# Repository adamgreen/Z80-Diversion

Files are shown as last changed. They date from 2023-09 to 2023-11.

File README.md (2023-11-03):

# Z80 Diversion
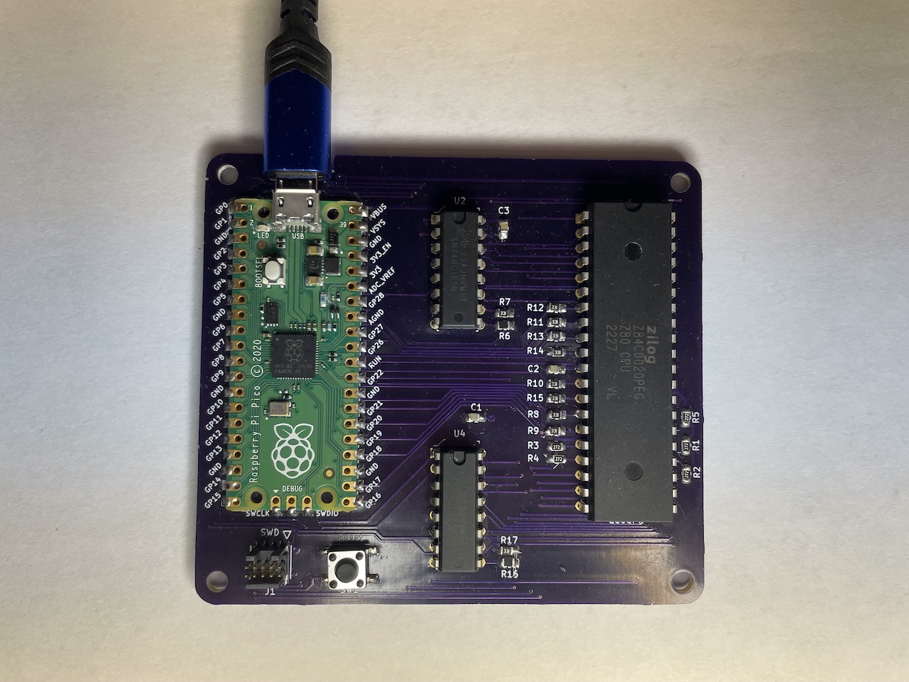
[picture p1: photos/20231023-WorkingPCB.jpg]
Photo of Working PCB


This project is a [Z80](https://www.zilog.com/index.php?Itemid=26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) based single board computer. A [RP2040 microcontroller](https://www.raspberrypi.com/documentation/microcontrollers/rp2040.html) is also included on the board. It is connected to the Z80 bus to:
* Provide the Z80 access to 64k of its 264k of SRAM.
* Allow a [Z80 compatible version of GDB](https://github.com/b-s-a/binutils-gdb) to debug the Z80 over a USB serial connection. The RP2040 is used as a hardware debugger for the Z80 much like modern JTAG or SWD probes (ie. Segger J-Link).

## Project Purpose
I want to verify some unit tests which exercise all of the instructions supported by the Z80 microprocessor. These tests can be used to verify Z80 emulation. Having the ability to also runs these tests against real Z80 hardware is desireable as it allows verifying the quality of the tests themselves. A few years ago, I did something similar for the ARMv6-M instruction tests that I wrote for my [pinkySim project](https://github.com/adamgreen/pinkySim).

## Project Progression
* The Z80, RP2040 Pico, and SN74HC165 shift register devices arrived from Digikey.
* I completed the initial schematic in KiCAD.
* I wired up an initial test version on my breadboard.
* I wrote simple proof of concept PIO and ARM code for the RP2040 to verify my hardware setup.
* I completed the initial PCB design in KiCAD.
* I ordered and received PCBs from [OSHPark](https://oshpark.com).
* I was able to download a [Z80 port of binutils/GDB](https://github.com/b-s-a/binutils-gdb) and build it on my Mac.
* I soldered up one of the PCBs and successfully tested it out with the code that I had previously developed.
* I simplified the PIO state machine code and got it running faster:
  * Can run the Z80 at 500kHz without requiring any wait cycles.
  * Can run the Z80 at faster clock rates (at least 5MHz) reliably but requires wait cycles as the RP2040 takes time to wait for the shift registers and respond to memory read/write requests.
* My [MRI core](https://github.com/adamgreen/mri) has been extended to handle debug targets which aren't just 32-bit. This will allow 64-bit in the future and 16-bit for Z80 debugging.
* The Z80 version of GDB is now able connect to the board via a RP2040 USB based serial connection to:
  * Examine and modify the Z80's 64k of RAM (which is actually a 64k global buffer on the RP2040).
  * Examine and modify the Z80's registers.
  * Single step the Z80.
  * Set up to 4 Code Breakpoints.
  * Set up to 2 Data Watchpoints
  * Z80 reset from GDB.

## Reading List
Build Your Own Z80 Computer Book Cover<br>
It has been around a decade since I last looked at the Z80 so I had to skim through a few Z80 references to refresh my memory of what it takes to interface this little guy to the outside world. These references included:
* [Build Your Own Z80 Computer by Steve Ciarcia](https://en.wikipedia.org/wiki/Build_Your_Own_Z80_Computer) ([Free PDF](http://www.pestingers.net/pdfs/other-computers/build-your-own-z80.pdf)).
* [Z80 CPU User Manual](https://www.zilog.com/docs/z80/UM0080.pdf)
* [Z80 Product Specification](https://www.zilog.com/docs/z80/ps0178.pdf)
* [Other Official Z80 Documents](https://www.zilog.com/index.php?Itemid=26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)

I also skimmed some RP2040 documentation again as well to make sure that I had a good chance of successfully interfacing it to the Z80 before going too far down that path:
* [Raspberry Pi Pico Datasheet](https://datasheets.raspberrypi.com/pico/pico-datasheet.pdf)
* [RP2040 Datasheet](https://datasheets.raspberrypi.com/rp2040/rp2040-datasheet.pdf)

## High Level BOM
This board includes:
* A **Z80 Microprocessor** - I am using a [Z84C0020PEG](https://www.digikey.com/en/products/detail/zilog/Z84C0020PEG/928994) device since it is:
  * 20 MHz capable. I picked the fastest CMOS version of the device available. It can run at 20MHz when powered by a 5V supply but it should be able to run at a lower 3.3V (same as the RP2040) when clocked at lower frequencies (between 1 and 2.5 MHz).
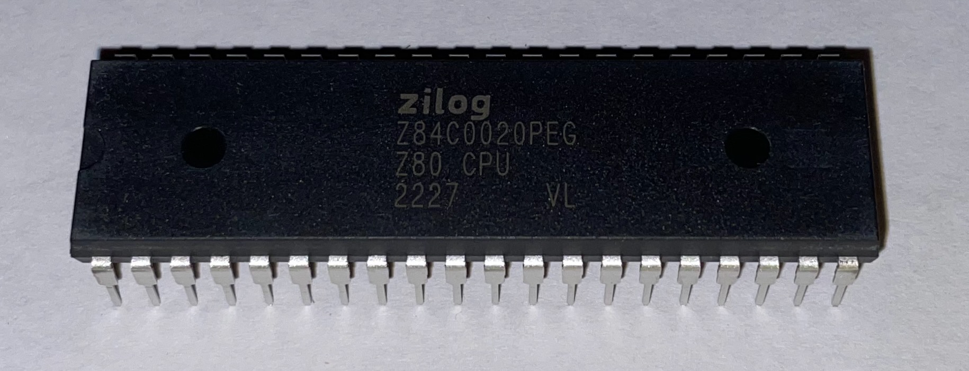
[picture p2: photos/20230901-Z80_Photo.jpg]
Photo of Z80 IC
  * 40-pin DIP package. Currently Digikey only has the DIP version of the 20MHz capable part in stock. I would have preferred the LQFP SMD version but it doesn't look like it will be in stock for awhile. It did make early bread boarding possible though.<br>
* A [RP2040 based Pico](https://www.digikey.com/en/products/detail/raspberry-pi/SC0915/13624793). This is connected to the Z80 bus and used to service Z80 memory requests. It also functions as a hardware debugger for the Z80. Features of the RP2040 that have been leveraged for this project include:
  * USB 1.1 controller and PHY. This allows for easy connection to a desktop/laptop. GDB can be used to program and debug the Z80 over this USB connection.
  * 264kB SRAM. 64kB of this is used to service memory read/write requests from the Z80.
  * 2MB of FLASH. Lots of room for the required firmware and storage of any ROM images that we may want to use with the Z80.
  * Programmable I/O. This was useful for interfacing with the Z80 bus without bit banging everything from the CPU.
  * Dual core Cortex-M0+ cores. Allowed dedicating a core to just servicing memory read/writes requests from the Z80. This way things like USB interrupts don't introduce random delays.
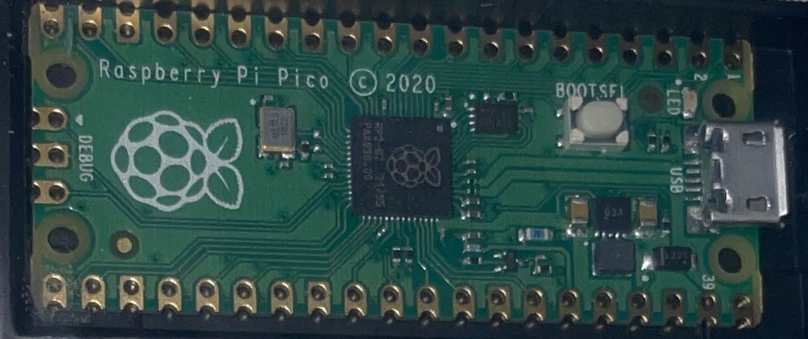
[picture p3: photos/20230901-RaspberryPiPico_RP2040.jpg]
Photo of Raspberry Pi Pico
  * The Pico has the required voltage regulation to allow the board to be powered directly from USB.<br>
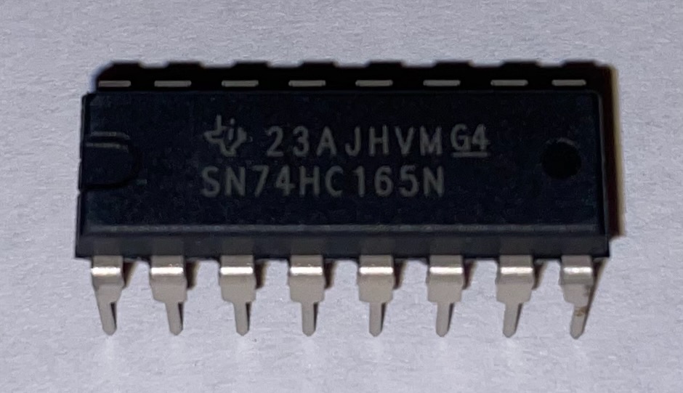
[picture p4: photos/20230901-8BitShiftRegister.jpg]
Photo of 8-bit Shift Register
* 2 x [SN74HC165 8-bit shift registers](https://www.digikey.com/en/products/detail/texas-instruments/SN74HC165N/376966). This is used to latch the 16-bit address sent from the Z80 and push it into the RP2040 over 2 serial lines, one for the even bits and the other for the odd bits. I run this chip at 5V and run the serial outputs through a 3/5 voltage divider to make it compatible with the RP2040 while also allowing it to run faster. The voltage divider did end up slowing down the rise/fall times but running it at 3.3V slowed it down even more. I ended up clocking the shift registers at ~15MHz with an asymmetric clock. I hold it high for longer so that the output has time to stabilize before I sample it from the RP2040 on the falling clock edge. I would like to switch to a faster shift register in future revisions.<br>

## Programmable I/O
One of the coolest features of the RP2040 is its Programmable I/O (PIO). If you look at the block diagram of many peripherals on a microcontroller, you tend to see the same parts: inbound and outbound FIFOs, shift registers, pin I/O, and a **state machine**. The PIO has all of the same parts except that its state machine is programmable.

I leverage the programmable I/O (PIO) peripheral on the RP2040 for interfacing to the Z80 bus. I use 2 PIO state machines for this interfacing:
* The first state machine, ```AddressStateMachine```, samples the **MREQ'** / **IOREQ'** signals and shifts out the 16-bit address bits using two 8-bit shift registers:
  * It pauses if it sees **RFSH'** asserted (pulled low) since those requests are just for refreshing DRAM which can be safely ignored. Once this signal is de-asserted the state machine starts running again.
  * If it sees either of the **MREQ'** or **IOREQ'** signals go active (pulled low) then it asserts the **WAIT'** signal to let the Z80 know that it needs to wait for the RP2040 to access the requested data.
  * It will then latch the 16-bit address bits and start shifting out the address, two bits at a time.
  * Once the 16-bit address has been fully shifted in, it will be pushed to the RX FIFO for the CPU to pick up.
  * The state machine will then wait for the CPU to send back the PIO instruction that either waits on the **MREQ'** or **IOREQ'** signal being de-asserted.
  * Before executing the wait instruction it de-asserts the **WAIT'** signal to let the Z80 know that the request has been completed.
  * It then waits for the **MREQ'** or **IOREQ'** signal to be de-asserted (pulled high again) before looping around and looking for the next request. The CPU assembles the correct ```WAIT 1 GPIO n``` instruction and sends it down to the PIO state machine via its TX FIFO.
* The other state machine, ```ReadWriteStateMachine```, samples the **RD'**/**WR'** signals to determine if a read or write memory transfer is being requested by the Z80:
  * It keeps sampling the **RD'**/**WR'** signals until it sees one of them go active (pulled low).
  * The state of the **RD'**, **WR'**, **D0** - **D7** and **M1'** lines are then transferred to the CPU so that between this data and the 16-bit address from the other state machine, the CPU has enough information to perform the memory request.
  * The state machine will then wait for the CPU to send back the required response. This will include bits needed for setting **D0**-**D7** to the correct input/output state, the requested byte if a read request was made, bits to set **D0**-**D7** back to input only, and a PIO instruction that waits on the **RD'** or **WR'** signal being de-asserted.

## Current Pin Map
The PIO state machines place constraints on some signals as they will need to be mapped to consecutively numbered GPIO pins so that they can be shifted in/out as a unit. This is how the pins ended up being mapped between the RP2040 and Z80:
| RP2040 | Z80 / Shift | PIO Pin Group | Notes |
|---|---|---|---|
| GP0  | Shift_In_Even | Input | |
| GP1  | Shift_In_Odd  | Input | |
| GP2  | MREQ' | Input | |
| GP3  | IOREQ' | Input | |
| GP4  | CLK | Set | |
| GP5  | Shift_Clock | Side Set | |
| GP6  | Shift_Latch | Side Set | |
| GP7  | RD' | Input | |
| GP8  | WR' | Input | |
| GP9  | D0 | Input/Output | |
| GP10 | D1 | Input/Output | |
| GP11 | D2 | Input/Output | |
| GP12 | D3 | Input/Output | |
| GP13 | D4 | Input/Output | |
| GP14 | D5 | Input/Output | |
| GP15 | D6 | Input/Output | |
| GP16 | D7 | Input/Output | |
| GP17 | M1' | Input | |
| GP18 | WAIT' | Set | 2.2kΩ Pull-Up |
| GP19 | RFSH' | WAIT GPIO | |
| GP20 | HALT' | Input / Non-PIO  | |
| GP21 | NMI' | Output / Non-PIO | 2.2kΩ Pull-Up |
| GP22 | INT' | Output / Non-PIO | 2.2kΩ Pull-Up |
| GP26 | RESET' | Output / Non-PIO | 3 CLK Long Pulse (3µs @ 1MHz) |
| N/C  | BUSREQ' | Not Connected | 2.2kΩ Pull-Up |

## Current Schematic
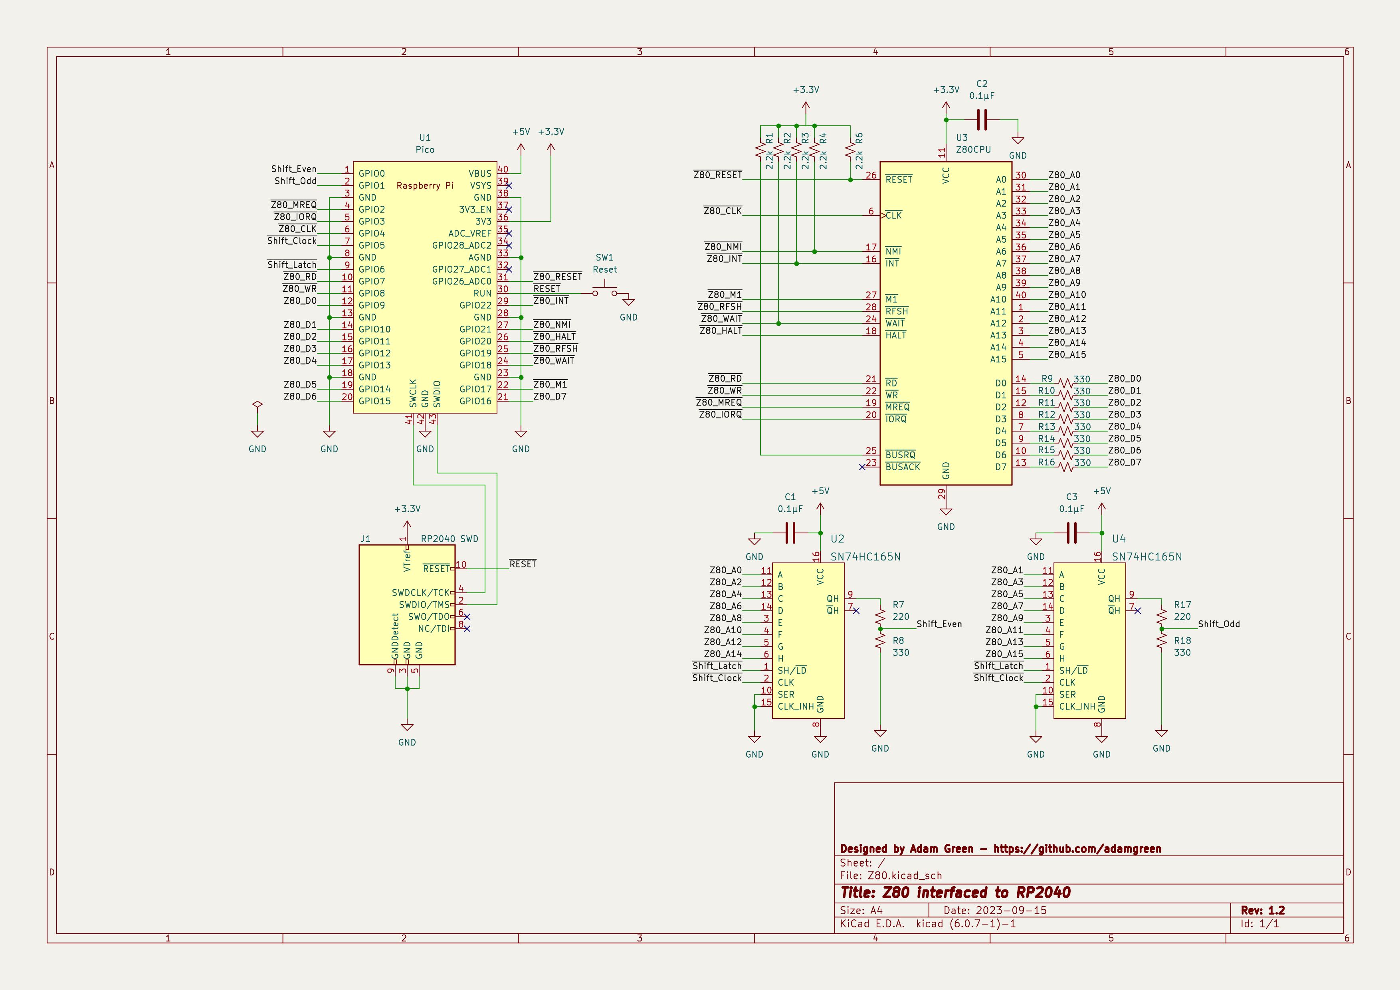
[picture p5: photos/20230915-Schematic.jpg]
Current Schematic
<br>
After wiring up this circuit on a breadboard, I found that things worked better if I made some changes to my original schematic:
* I originally thought it would work best to shift in the Z80 address bit pairs in from least significant to most significant. This results in the CPU receiving the address in the upper 16 bits and the **MREQ'** and **IOREQ'** signals values in bits 14-15. It would be nicer if the address bits were in the lower 16-bits where they can be easily masked off and used. Doing the shifts in this order required me reversing the order of the Z80 address bit connections to each of the shift registers.
* I added 0.1µF bypass capacitors to the IC power supply lines.
* I discovered that the SN74HC165 shift registers didn't have output rise and fall times that were consistent with running them at 50MHz even though I was supplying them with 5V.
  * The high resistance voltage divider I had in the original schematic to level shift this output made the problem worse.
  * Reducing the voltage divider from 55kΩ to 550Ω did shorten the rise and fall times but not enough to work at 50MHz. It does work up to 15MHz now though.
  * If I switch to SMD parts then I think there are variants of the 74*165 shift registers that can run at 3.3V and give the desired <= 10ns rise/fall times. I may try this in the future but I will just use the parts that I already have for now.
* I also wanted to test that the Z80 runs reliably at 3.3V with lower clock rates. The Z80 didn't hit any issues running NOPs at 400kHz on this breadboard setup. After I rewrote the PIO code when working with the PCB version of this circuit I was able to run it successfully at 5MHz.
* I removed the 330Ω pull-up resistor from the **CLK** signal. It was needed for TTL clocking circuits used with the older NMOS version of the Z80. I am using a CMOS version of the Z80 and driving **CLK** directly from a pin of the CMOS based RP2040 microcontroller so it isn't needed anymore.

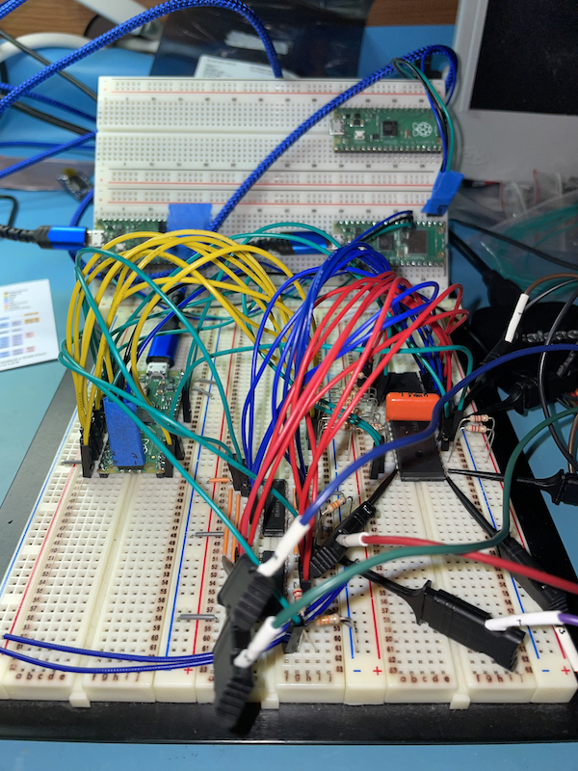
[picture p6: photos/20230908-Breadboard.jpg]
Photo of Breadboard Setup


The screenshot below shows some early traces from my logic analyzer as I began to get the Z80 successfully starting up on the breadboard above and executing NOPs supplied by the RP2040.

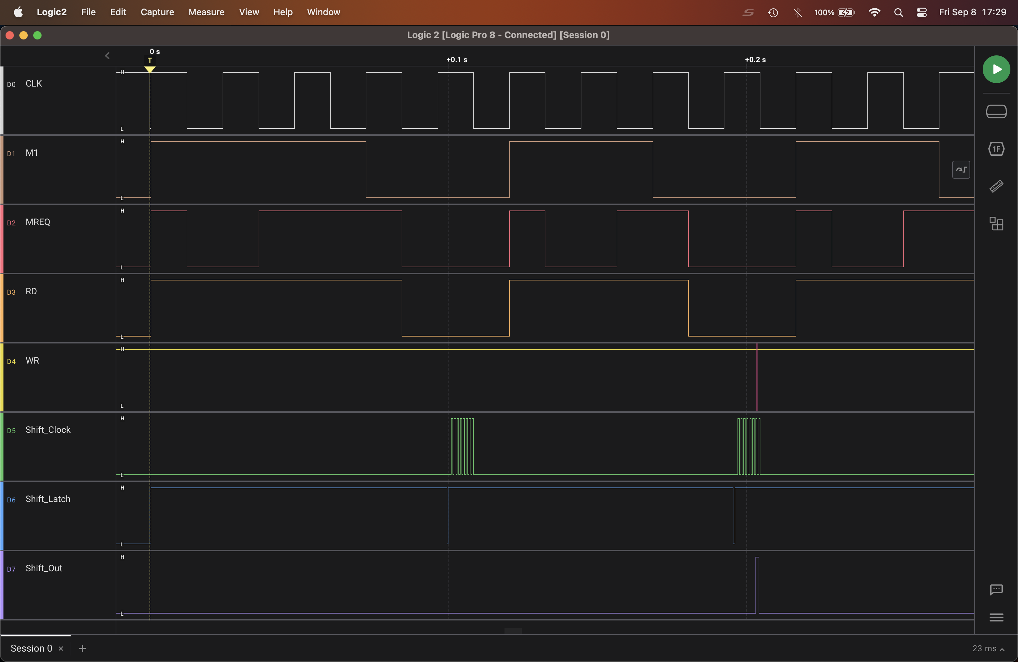
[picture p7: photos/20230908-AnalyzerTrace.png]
Initial Trace


## PCB Design version 1.1
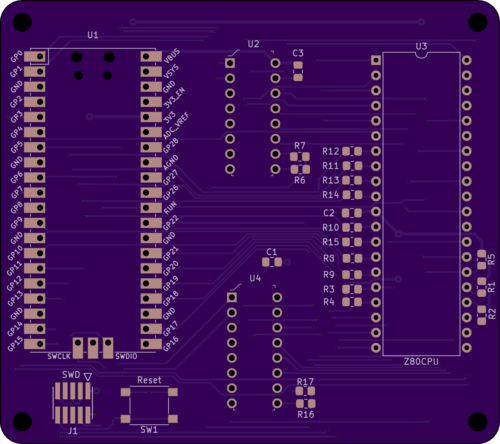
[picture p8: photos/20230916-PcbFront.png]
OSHPark rendering of PCB Front
<br>
I completed the initial PCB design and sent it off to OSHPark to have it fabricated. It was a lot easier to work with this board than the previous mess of wires I had on my breadboard.

### Issues Discovered in Version 1.1 PCB
After soldering up the first of the version 1.1 PCBs I encountered an issue:
* When soldering the Raspberry Pi Pico to the PCB as a surface mount part there isn't enough clearance between the bottom of the USB connector on the Pico and my PCB.
  * I had to file out a groove to have it work with my USB cable on the first board I soldered up since I had already soldered the Pico down flat to the PCB surface.
  * On subsequent assemblies of this version of the PCB I will use male headers to mount the Pico as a through hole part (the footprint allows both SMD and through hole mounting). This will lift the Pico up off of the PCB to make room for the USB cable housing.
  * If I make another version of this PCB, I will align the Pico's USB connector with the edge of the PCB to eliminate this issue.

## GDB for Z80
I have past experience with using GDB and GDB debug stubs to debug Cortex-M microcontrollers. I leveraged this experience to support GDB debugging of the Z80 on this board. When I tested my ARMv6-M instruction tests on real Cortex-M hardware, I used an existing GDB debug stub and modified my test harness to pretend to be GDB so that it could place required inputs and code into RAM, setup the registers, single step over the test instruction, and then interrogate memory and registers afterwards to verify that the expected side effects occurred. I can now do the same for the Z80 using this project.

I found the following page on the web and it had lots of great information on how to use GDB with the Z80:
* [chciken's TLMBoy: Implementing the GDB Remote Serial Protocol](https://www.chciken.com/tlmboy/2022/04/03/gdb-z80.html)

### Building GDB for Z80
I have been able to download and build the same Z80 fork as @chciken:
* ```git clone https://github.com/b-s-a/binutils-gdb.git z80-gdb```
* Apply the following diff to allow the Z80 version of GDB to handle SP being set to 0x0000:
```diff
diff --git a/gdb/z80-tdep.c b/gdb/z80-tdep.c
index 641af5e06c..42f04c49f0 100644
--- a/gdb/z80-tdep.c
+++ b/gdb/z80-tdep.c
@@ -663,6 +663,7 @@ z80_frame_unwind_cache (struct frame_info *this_frame,
       /* Assume that the FP is this frame's SP but with that pushed
         stack space added back.  */
       this_base = get_frame_register_unsigned (this_frame, Z80_SP_REGNUM);
+      if (this_base == 0x0000) this_base = 1 << gdbarch_ptr_bit(gdbarch);
       sp = this_base + info->size;
       if (this_base < sp_min || sp > sp_max)
          return info;
```
* ```brew install texinfo```
* ```cd z80-gdb```
* ```mkdir build/```
* ```cd build/```
* ```LDFLAGS=-Bstatic ../configure --target=z80-unknown-elf --disable-werror --prefix=$(pwd) --exec-prefix=$(pwd)```
* ```make```
* **Note:** I don't have ```make install``` working on macOS yet. Until then, the GDB binary can be found as ```z80-gdb/build/gdb/gdb```

### Using GDB for Z80
This section shows a few snippets from an example GDB session where it is attached to my Z80 board and uses them to explain some of the debug operations supported by my firmware.

* First I will start the Z80 version of GDB that I talked about building up above. It instructs GDB to connect to a remote target using a virtual serial port, ```/dev/cu.usbmodem111301``` on my machine. GDB will give a warning about ```"No executable has been specified and target does not support determining executable automatically."``` because no .ELF file was provided. This means we have no symbols but we can still look at the low level assembly instructions, Z80 registers, and memory contents to figure out what our program is doing.
* The firmware in my board is currently written so that it loads a little test program into memory at address 0, where the Z80 starts executing upon power up, hardware reset, and ```RST 0``` commands. This sample program loads known values into all of the registers.
* The current debugger firmware also halts the Z80 when it comes out of reset, before it can even execute the first instruction at address 0x0000.
* The first command I give GDB is ```x/24i 0x0000``` This asks GDB to dump the first 24 **i**nstructions starting at address 0x0000.
  * The disassemble instruction doesn't work because it requires symbols to know where a function starts and we don't have a .ELF to provide those symbols.
  * This lets us see the contents of the test program used to load known values into the registers.
```
~/depots/Z80-Diversion$ ~/depots/z80-gdb/build/gdb/gdb -ex "set target-charset ASCII" -ex "set remotelogfile z80_mri.log" -ex "target remote /dev/cu.usbmodem111301"
GNU gdb (GDB) 10.0.50.20200317-git
Copyright (C) 2020 Free Software Foundation, Inc.
License GPLv3+: GNU GPL version 3 or later <http://gnu.org/licenses/gpl.html>
This is free software: you are free to change and redistribute it.
There is NO WARRANTY, to the extent permitted by law.
Type "show copying" and "show warranty" for details.
This GDB was configured as "--host=arm-apple-darwin22.6.0 --target=z80-unknown-elf".
Type "show configuration" for configuration details.
For bug reporting instructions, please see:
<http://www.gnu.org/software/gdb/bugs/>.
Find the GDB manual and other documentation resources online at:
    <http://www.gnu.org/software/gdb/documentation/>.

For help, type "help".
Type "apropos word" to search for commands related to "word".
Remote debugging using /dev/cu.usbmodem111301
warning: No executable has been specified and target does not support
determining executable automatically.  Try using the "file" command.
0x00000000 in ?? ()
(gdb) x/24i 0x0000
=> 0x0:	ld sp,0x0000
   0x3:	ld a,0x14
   0x5:	ld i,a
   0x7:	ld a,0x15
   0x9:	ld r,a
   0xb:	ld bc,0x0001
   0xe:	push bc
   0xf:	pop af
   0x10:	ld bc,0x0203
   0x13:	ld de,0x0405
   0x16:	ld hl,0x0607
   0x19:	ld ix,0x0809
   0x1d:	ld iy,0x0a0b
   0x21:	exx
   0x22:	ex af,af'
   0x23:	ld bc,0x0c0d
   0x26:	push bc
   0x27:	pop af
   0x28:	ld bc,0x0e0f
   0x2b:	ld de,0x1011
   0x2e:	ld hl,0x1213
   0x31:	ex af,af'
   0x32:	exx
   0x33:	jr 0x0033
```

* The next command I send to GDB is ```info reg``` to dump all of the Z80 registers at once. This version of GDB exposes all Z80 registers as 16-bit quantities so the value of an 8-bit register like A can be found in the combined 16-bit AF register.
  * It shows that the ```PC``` register is currently set to 0x0 as expected when first coming out of reset.
  * The rest of the registers will be given specific values as the test program runs and we can check these later once the program completes execution and enters the infinite loop at the end.
```
(gdb) info reg
af             0x1401              [ C ]
bc             0x1495              5269
de             0x1011              0x1011
hl             0x1213              0x1213
sp             0xffe8              0xffe8
pc             0x0                 0x0
ix             0x809               0x809
iy             0xa0b               0xa0b
af'            0x1401              [ C ]
bc'            0x203               515
de'            0x405               0x405
hl'            0x607               0x607
ir             0x0                 0
```

* I have implemented support for 4 hardware code breakpoints and 2 hardware data watchpoints.
  * Below I use the ```watch *(int*)0xfffe``` command to set a watchpoint to trigger when a 16-bit integer is written to the top slot on the stack. If we look at the disassembly of the code that was dumped above, we see that the SP is set to 0x0000 by the first instruction so the first 16-bit write will occur at 0x0000-2 which underflows to a value of 0xFFFE. The ```rwatch``` and ```awatch``` commands are also supported for watchpoints on reads or accesses (reads or writes).
  * The Z80 version of GDB considers ```short``` and ```char``` to both be 8-bit values and ```int``` to be 16-bit. That's why the stack address is cast to a ```int``` in the ```watch``` command.
  * The ```break *0x32``` command below sets a breakpoint on the ```EXX``` instruction at 0x0032.

```
(gdb) watch *(int*)0xfffe
Hardware watchpoint 1: *(int*)0xfffe
(gdb) break *0x32
warning: Unable to determine inferior's software breakpoint type: couldn't find `_break_handler' function in the executable. Will be used default software breakpoint instruction RST 0x08.
Breakpoint 2 at 0x32
```

* The next GDB command, ```disp/1i $pc```, instructs GDB to dump the current Z80 instruction when execution is halted into the debugger. This is very useful when single stepping through the code.
```
(gdb) disp/1i $pc
1: x/i $pc
=> 0x0:	ld sp,0x0000
```

* We can now use the **si** instruction to single step through the machine code, 1 instruction at a time.
  * While my debug hardware can perform a low level hardware single step, the Z80 version of GDB is written expecting this to be difficult for Z80 based debug monitors so it interprets the next Z80 instruction to be executed. It determines what address the ```PC``` register will contain after it is executed and sets a breakpoint on that address.
```
(gdb) si
0x00000003 in ?? ()
1: x/i $pc
=> 0x3:	ld a,0x14
(gdb)
0x00000005 in ?? ()
1: x/i $pc
=> 0x5:	ld i,a
```

* I now give GDB the ```c``` command to continue execution as normal (no more single stepping). This will cause it to run until we CTRL+C to force a break or a breakpoint/watchpoint is encountered.
* It first stops when the first new value of ```1``` is pushed onto the top of the stack. It should be noted that watchpoints always cause the Z80 to halt on the next instruction executed after the memory access occurred and not on the instruction which actually performed the memory read or write. For example here we see it halt on a ```POP``` instruction but it was actually the previous ```PUSH``` instruction that actually wrote the new value to the stack.
```
(gdb) c
Continuing.

Hardware watchpoint 1: *(int*)0xfffe

Old value = 0
New value = 1
0x0000000f in ?? ()
1: x/i $pc
=> 0xf:	pop af
```

* It then stops when that position on the stack is overwritten yet again.
```
(gdb) c
Continuing.

Hardware watchpoint 1: *(int*)0xfffe

Old value = 1
New value = 3085
0x00000027 in ?? ()
1: x/i $pc
=> 0x27:	pop af
```

* This time the Z80 is halted when it gets to the instruction at address 0x32, the address on which breakpoint #2 was set previously.
```
(gdb) c
Continuing.

Breakpoint 2, 0x00000032 in ?? ()
1: x/i $pc
=> 0x32:	exx
```

* If we continue execution now, the Z80 will enter an infinite loop with the ```JR 0x0033``` instruction.
* To halt the Z80 so that we can look at its current state, we need to press CTRL+C in GDB to interrupt the Z80's current execution and halt into the debugger.
* The output from GDB shows that the Z80 was executing the infinite loop at 0x33 as expected.
```
(gdb) c
Continuing.
^C
Program received signal SIGINT, Interrupt.
0x00000033 in ?? ()
1: x/i $pc
=> 0x33:	jr 0x0033
```

* At this point I send the ```info reg``` command again to look at the contents of all the Z80 registers and see that they match the values that were placed in them with the little test program dumped at the beginning of this debug session: 0x00 in A, 0x01 in F, 0x02 in B, 0x03 in C, etc.
```
(gdb) info reg
af             0x1                 [ C ]
bc             0x203               515
de             0x405               0x405
hl             0x607               0x607
sp             0x0                 0x0
pc             0x33                0x33
ix             0x809               0x809
iy             0xa0b               0xa0b
af'            0xc0d               [ C P/V F3 ]
bc'            0xe0f               3599
de'            0x1011              0x1011
hl'            0x1213              0x1213
ir             0x14f7              5367
```

* The ```dump ihex memory``` command can be used to dump a specific section of memory to a .hex file. The following snippet shows dumping all 64k of memory to a file named ```test.hex```
```
(gdb) dump ihex memory test.hex 0 0x10000
(gdb) shell ls -l *.hex
-rw-r--r--  1 foobar  staff  184333 Nov  1 02:54 test.hex
```

* Such a dump can be used to write known values into memory at a later point in time using the ```restore``` command.
```
(gdb) restore test.hex
Restoring section .sec1 (0x0 to 0x10000)
```

* The ```monitor reset``` command can be used to assert the **RESET'** pin on the Z80 to force a hardware reset.
    * Breakpoints and watchpoints set before the reset are still active after the reset. This means that you can set a breakpoint at address 0x0000 to cause the Z80 to halt as soon as it comes out of reset if you want to step through your reset code.
    * The actual reset doesn't actually occur until the next ```continue``` command is sent from GDB.
```
(gdb) break *0
Breakpoint 3 at 0x0
(gdb) monitor reset
Will reset on next continue.
(gdb) c
Continuing.

Breakpoint 3, 0x00000000 in ?? ()
```

## Next Steps
* Start using the board to validate Z80 emulation unit tests.

## Potential Future Improvements?
* Use shift registers that can shift at faster rates when run at 3.3V. This is one of the things that is most limiting the performance of the current design. The CPU cycles it takes for the RP2040's Cortex-M0 core to respond to memory requests is the other but faster addressing shifting gives the CPU even more buffer.
* The board could be made smaller and look more consistent if the Z80 and shift registers were surface mount as well.

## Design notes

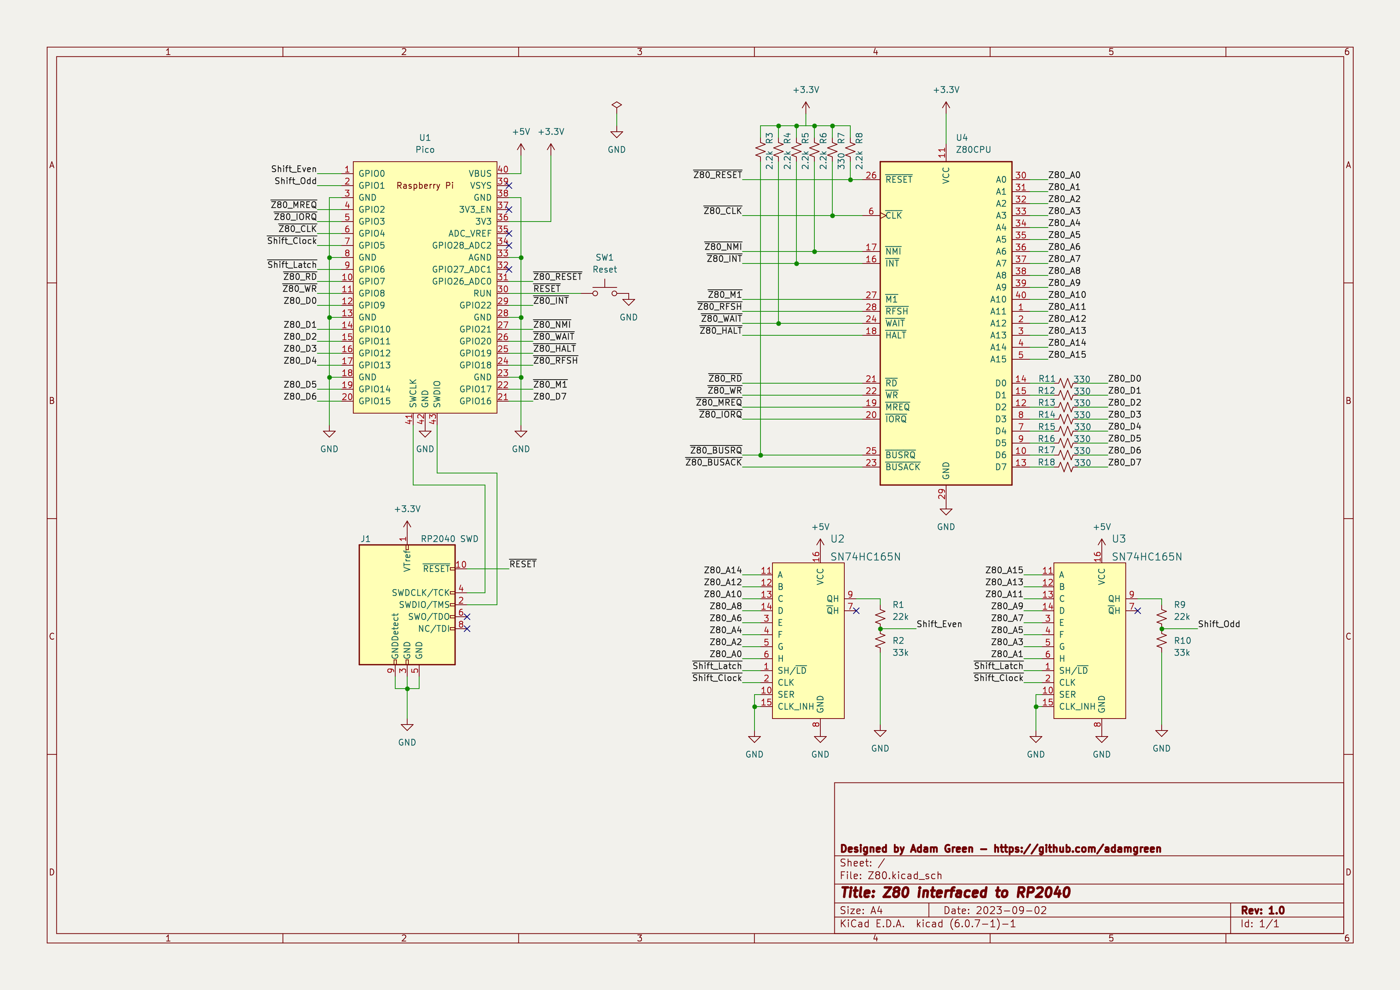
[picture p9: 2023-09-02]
photos/20230902-Schematic.jpg

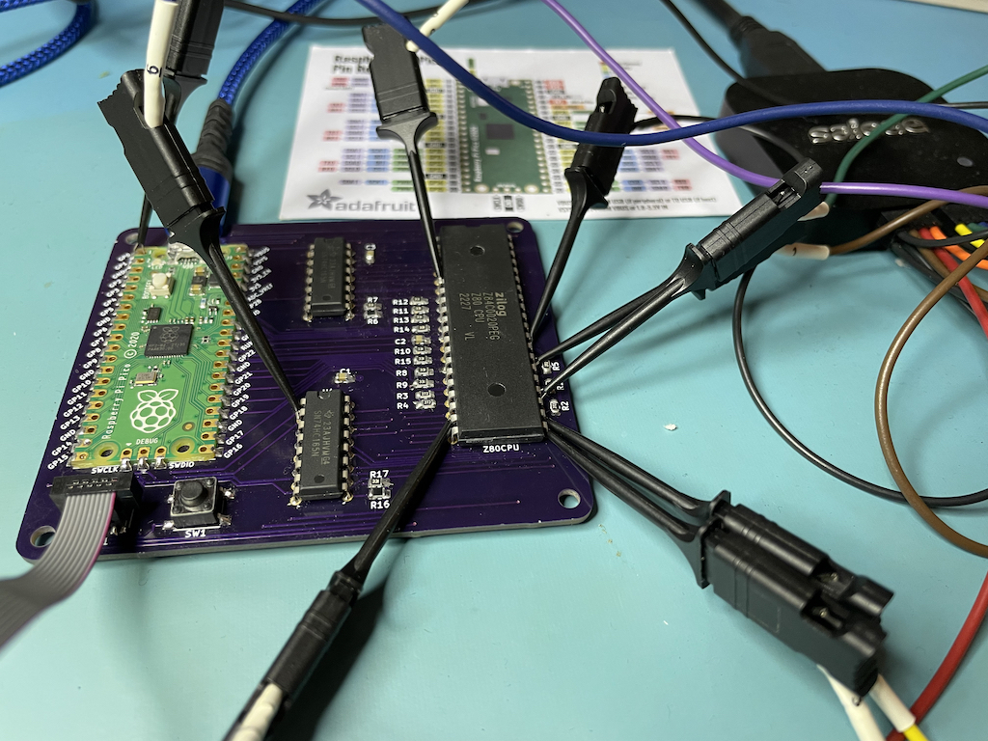
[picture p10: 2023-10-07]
photos/20231007-FirstPCB.jpg

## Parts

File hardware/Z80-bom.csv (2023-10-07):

Source: | /Users/adamgreen/depots/Z80-Diversion/hardware/Z80.kicad_sch
Date: | Friday, October 06, 2023 at 06:04:24 PM
Tool: | Eeschema (6.0.7-1)-1
Generator: | /Applications/KiCad/KiCad.app/Contents/SharedSupport/plugins/bom_csv_grouped_by_value.py
Component Count: | 26
Individual Components:
Item | Qty | Reference(s) | Value | LibPart | Footprint | Datasheet | Category | DK_Datasheet_Link | DK_Detail_Page | Description | Digi-Key_PN | Family | MPN | Manufacturer | Status
 |  | C1 | 0.1µF | Device:C | Capacitor_SMD:C_0805_2012Metric_Pad1.18x1.45mm_HandSolder | ~
 |  | C2 | 0.1µF | Device:C | Capacitor_SMD:C_0805_2012Metric_Pad1.18x1.45mm_HandSolder | ~
 |  | C3 | 0.1µF | Device:C | Capacitor_SMD:C_0805_2012Metric_Pad1.18x1.45mm_HandSolder | ~
 |  | J1 | RP2040 SWD | Connector:Conn_ARM_JTAG_SWD_10 | SWD_footprints:CON10_2X5_DUK_FTSH_SAI | http://infocenter.arm.com/help/topic/com.arm.doc.ddi0314h/DDI0314H_coresight_components_trm.pdf
 |  | R1 | 2.2k | Device:R_Small_US | Resistor_SMD:R_0805_2012Metric_Pad1.20x1.40mm_HandSolder | ~
 |  | R2 | 2.2k | Device:R_Small_US | Resistor_SMD:R_0805_2012Metric_Pad1.20x1.40mm_HandSolder | ~
 |  | R3 | 2.2k | Device:R_Small_US | Resistor_SMD:R_0805_2012Metric_Pad1.20x1.40mm_HandSolder | ~
 |  | R4 | 2.2k | Device:R_Small_US | Resistor_SMD:R_0805_2012Metric_Pad1.20x1.40mm_HandSolder | ~
 |  | R5 | 2.2k | Device:R_Small_US | Resistor_SMD:R_0805_2012Metric_Pad1.20x1.40mm_HandSolder | ~
 |  | R6 | 220 | Device:R_Small_US | Resistor_SMD:R_0805_2012Metric_Pad1.20x1.40mm_HandSolder | ~
 |  | R7 | 330 | Device:R_Small_US | Resistor_SMD:R_0805_2012Metric_Pad1.20x1.40mm_HandSolder | ~
 |  | R8 | 330 | Device:R_Small_US | Resistor_SMD:R_0805_2012Metric_Pad1.20x1.40mm_HandSolder | ~
 |  | R9 | 330 | Device:R_Small_US | Resistor_SMD:R_0805_2012Metric_Pad1.20x1.40mm_HandSolder | ~
 |  | R10 | 330 | Device:R_Small_US | Resistor_SMD:R_0805_2012Metric_Pad1.20x1.40mm_HandSolder | ~
 |  | R11 | 330 | Device:R_Small_US | Resistor_SMD:R_0805_2012Metric_Pad1.20x1.40mm_HandSolder | ~
 |  | R12 | 330 | Device:R_Small_US | Resistor_SMD:R_0805_2012Metric_Pad1.20x1.40mm_HandSolder | ~
 |  | R13 | 330 | Device:R_Small_US | Resistor_SMD:R_0805_2012Metric_Pad1.20x1.40mm_HandSolder | ~
 |  | R14 | 330 | Device:R_Small_US | Resistor_SMD:R_0805_2012Metric_Pad1.20x1.40mm_HandSolder | ~
 |  | R15 | 330 | Device:R_Small_US | Resistor_SMD:R_0805_2012Metric_Pad1.20x1.40mm_HandSolder | ~
 |  | R16 | 220 | Device:R_Small_US | Resistor_SMD:R_0805_2012Metric_Pad1.20x1.40mm_HandSolder | ~
 |  | R17 | 330 | Device:R_Small_US | Resistor_SMD:R_0805_2012Metric_Pad1.20x1.40mm_HandSolder | ~
 |  | SW1 | Reset | Switch:SW_Push | Button_Switch_SMD:SW_Push_1P1T_NO_6x6mm_H9.5mm | ~
 |  | U1 | Pico | RPi_Pico:Pico | RPi_Pico:RPi_Pico_SMD_TH
 |  | U2 | SN74HC165N | dk_Logic-Shift-Registers:SN74HC165N | digikey-footprints:DIP-16_W7.62mm | http://www.ti.com/general/docs/suppproductinfo.tsp?distId=10 | Integrated Circuits (ICs) | http://www.ti.com/general/docs/suppproductinfo.tsp?distId=10 | /product-detail/en/texas-instruments/SN74HC165N/296-8251-5-ND/376966 | IC 8-BIT SHIFT REGISTER 16-DIP | 296-8251-5-ND | Logic - Shift Registers | SN74HC165N | Texas Instruments | Active
 |  | U3 | Z80CPU | CPU:Z80CPU | Package_DIP:DIP-40_W15.24mm | www.zilog.com/manage_directlink.php?filepath=docs/z80/um0080
 |  | U4 | SN74HC165N | dk_Logic-Shift-Registers:SN74HC165N | digikey-footprints:DIP-16_W7.62mm | http://www.ti.com/general/docs/suppproductinfo.tsp?distId=10 | Integrated Circuits (ICs) | http://www.ti.com/general/docs/suppproductinfo.tsp?distId=10 | /product-detail/en/texas-instruments/SN74HC165N/296-8251-5-ND/376966 | IC 8-BIT SHIFT REGISTER 16-DIP | 296-8251-5-ND | Logic - Shift Registers | SN74HC165N | Texas Instruments | Active
Collated Components:
Item | Qty | Reference(s) | Value | LibPart | Footprint | Datasheet | Category | DK_Datasheet_Link | DK_Detail_Page | Description | Digi-Key_PN | Family | MPN | Manufacturer | Status
1 | 3 | C1, C2, C3 | 0.1µF | Device:C | Capacitor_SMD:C_0805_2012Metric_Pad1.18x1.45mm_HandSolder | ~
2 | 1 | J1 | RP2040 SWD | Connector:Conn_ARM_JTAG_SWD_10 | SWD_footprints:CON10_2X5_DUK_FTSH_SAI | http://infocenter.arm.com/help/topic/com.arm.doc.ddi0314h/DDI0314H_coresight_components_trm.pdf
3 | 5 | R1, R2, R3, R4, R5 | 2.2k | Device:R_Small_US | Resistor_SMD:R_0805_2012Metric_Pad1.20x1.40mm_HandSolder | ~
4 | 2 | R6, R16 | 220 | Device:R_Small_US | Resistor_SMD:R_0805_2012Metric_Pad1.20x1.40mm_HandSolder | ~
5 | 10 | R7, R8, R9, R10, R11, R12, R13, R14, R15, R17 | 330 | Device:R_Small_US | Resistor_SMD:R_0805_2012Metric_Pad1.20x1.40mm_HandSolder | ~
6 | 1 | SW1 | Reset | Switch:SW_Push | Button_Switch_SMD:SW_Push_1P1T_NO_6x6mm_H9.5mm | ~
7 | 1 | U1 | Pico | RPi_Pico:Pico | RPi_Pico:RPi_Pico_SMD_TH
8 | 2 | U2, U4 | SN74HC165N | dk_Logic-Shift-Registers:SN74HC165N | digikey-footprints:DIP-16_W7.62mm | http://www.ti.com/general/docs/suppproductinfo.tsp?distId=10 | Integrated Circuits (ICs) | http://www.ti.com/general/docs/suppproductinfo.tsp?distId=10 | /product-detail/en/texas-instruments/SN74HC165N/296-8251-5-ND/376966 | IC 8-BIT SHIFT REGISTER 16-DIP | 296-8251-5-ND | Logic - Shift Registers | SN74HC165N | Texas Instruments | Active
9 | 1 | U3 | Z80CPU | CPU:Z80CPU | Package_DIP:DIP-40_W15.24mm | www.zilog.com/manage_directlink.php?filepath=docs/z80/um0080

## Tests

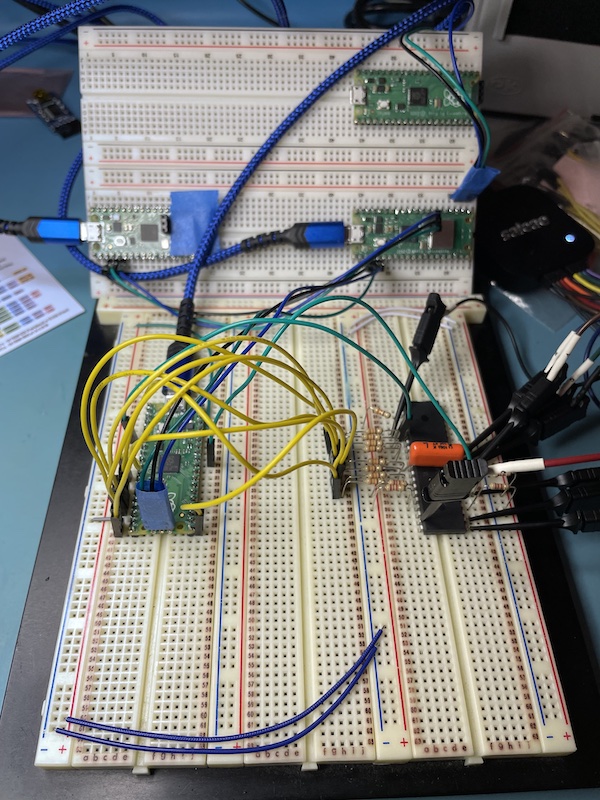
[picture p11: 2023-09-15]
photos/20230906-InitialBringupBreadboard.jpg

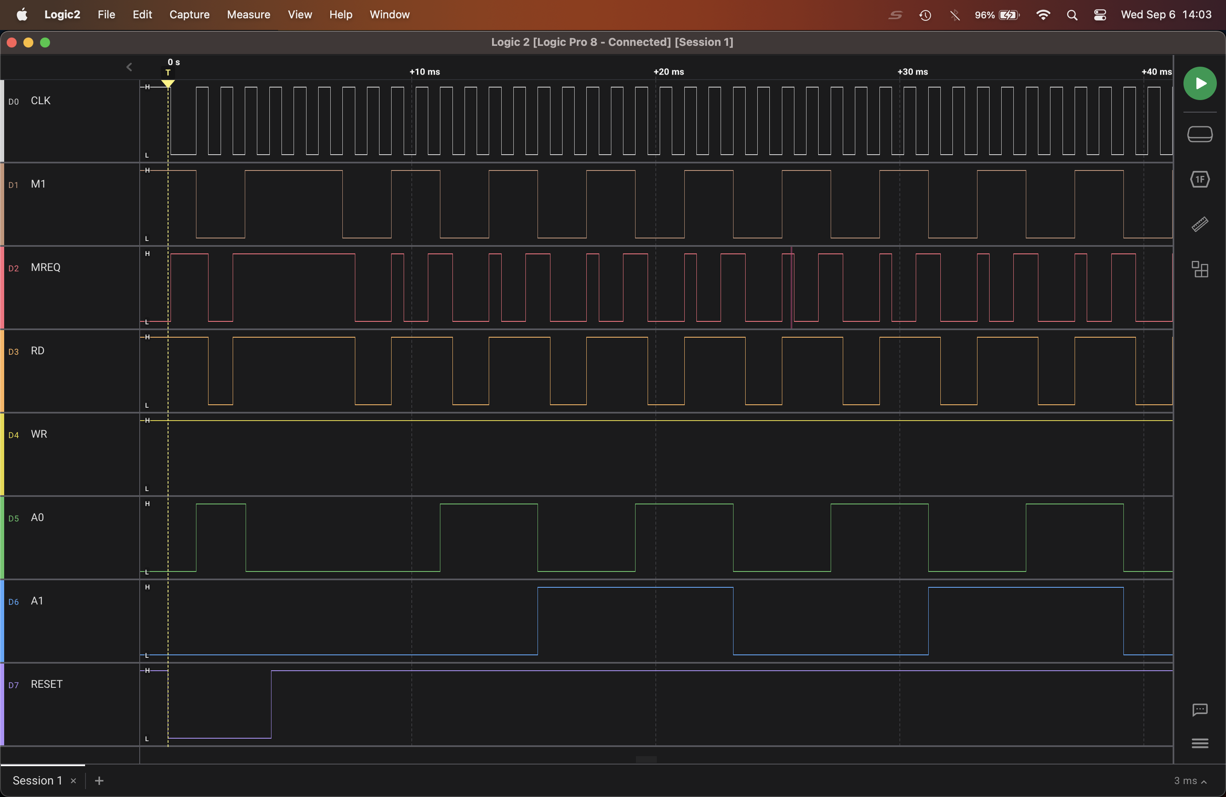
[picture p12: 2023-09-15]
photos/20230906-InitialBringupScreenshot.png

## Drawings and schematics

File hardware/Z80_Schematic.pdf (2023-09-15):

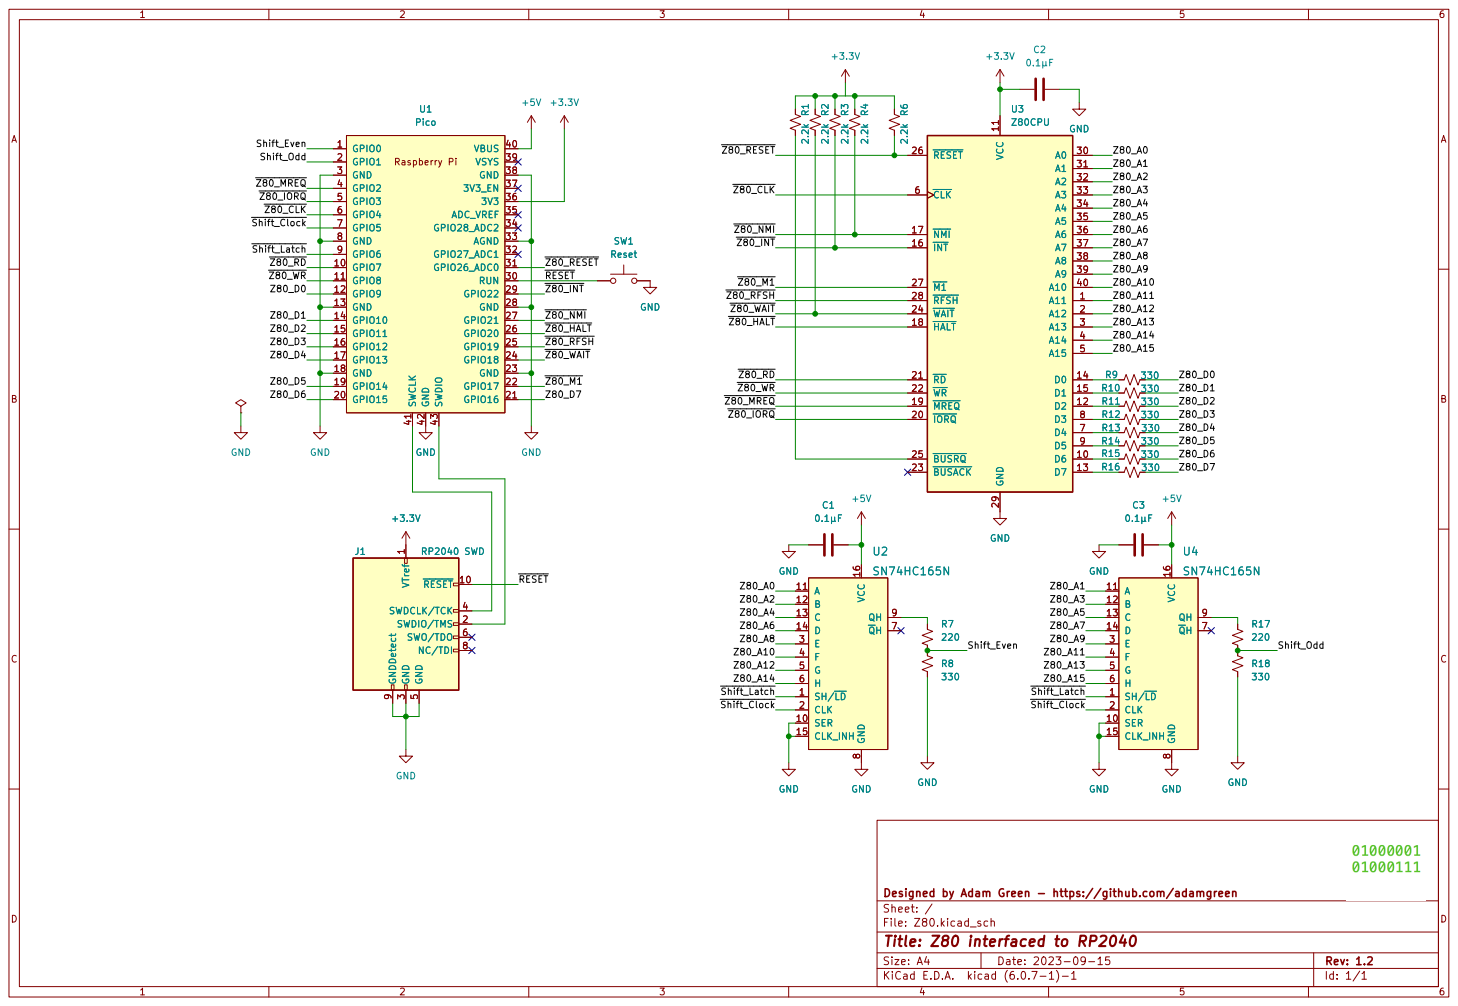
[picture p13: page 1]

5 SWO/TDO 6 NC/TDI 8 GNDDetect 9 +3.3V C1

8 QH 9 GND GND GND GND

8 QH 9 GND GND GND

5 SWO/TDO 6 NC/TDI 8 GNDDetect 9

Id: 1/1 Title: Z80 interfaced to RP2040

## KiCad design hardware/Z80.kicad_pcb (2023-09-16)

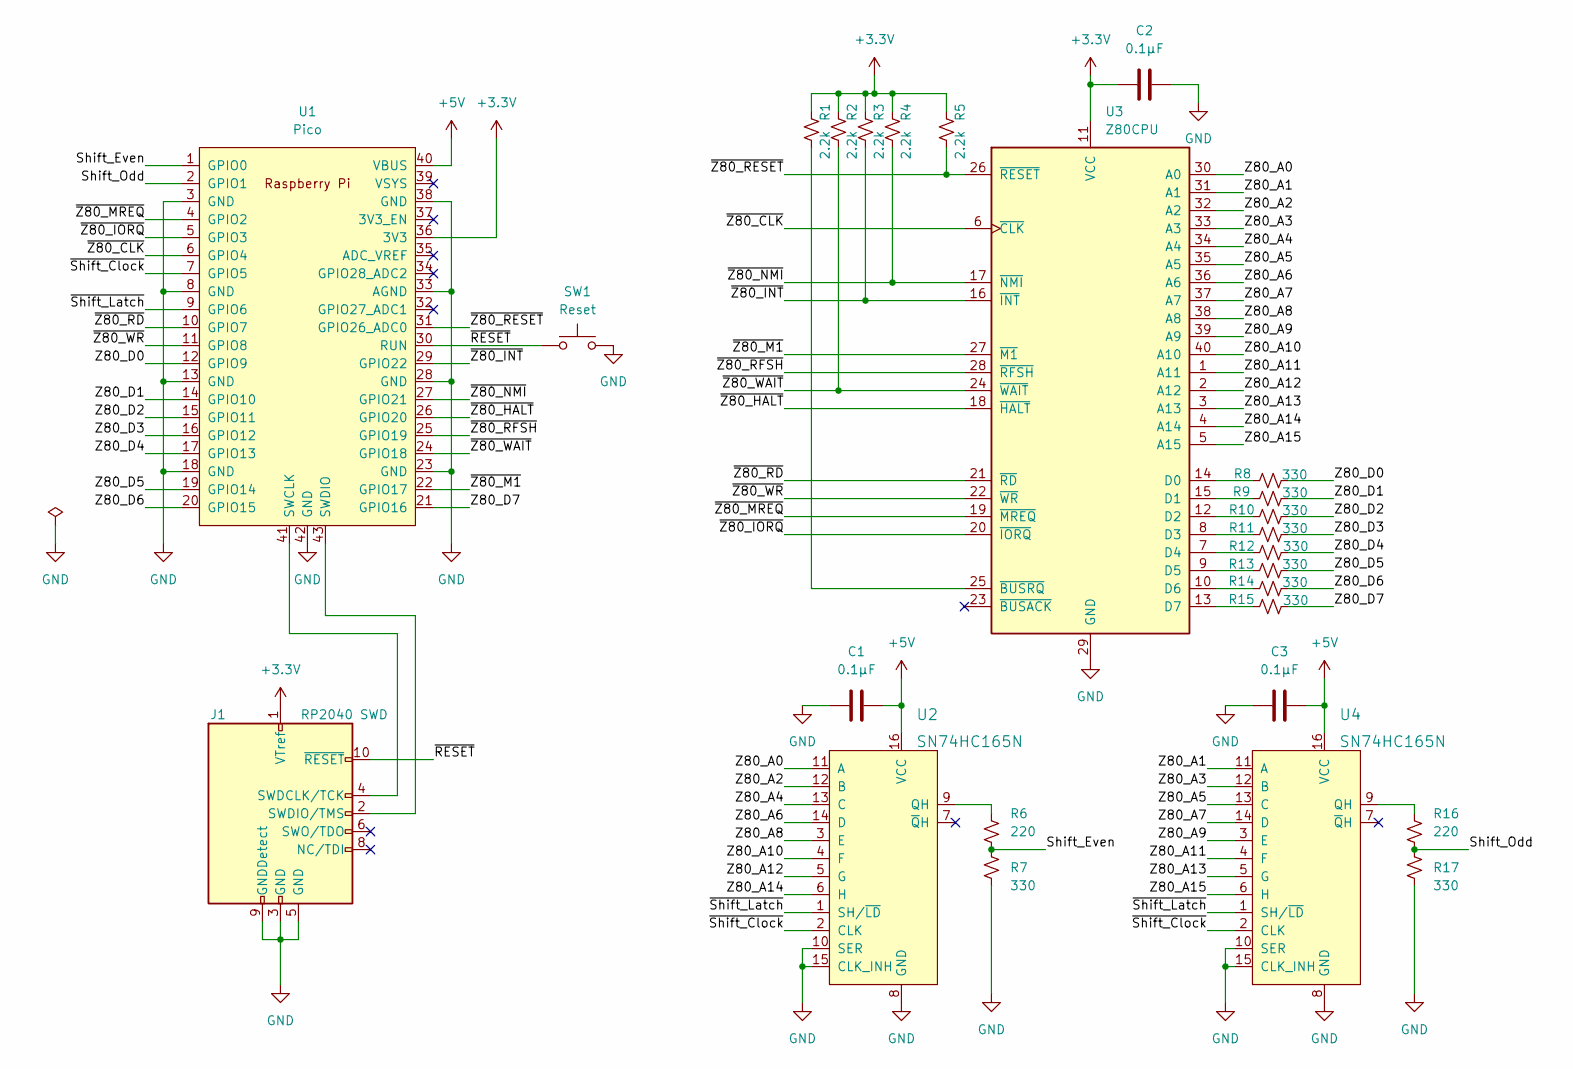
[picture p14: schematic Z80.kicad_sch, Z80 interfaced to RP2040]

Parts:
C1, C2, C3: 0.1µF; C_0805_2012Metric_Pad1.18x1.45mm_HandSolder
J1: RP2040 SWD; CON10_2X5_DUK_FTSH_SAI
R1, R2, R3, R4, R5: 2.2k; R_0805_2012Metric_Pad1.20x1.40mm_HandSolder
R6, R16: 220; R_0805_2012Metric_Pad1.20x1.40mm_HandSolder
R7, R8, R9, R10, R11, R12, R13, R14, R15, R17: 330; R_0805_2012Metric_Pad1.20x1.40mm_HandSolder
SW1: Reset; SW_Push_1P1T_NO_6x6mm_H9.5mm
U1: Pico; RPi_Pico_SMD_TH
U2, U4: SN74HC165N; DIP-16_W7.62mm; MPN SN74HC165N; Digi-Key_PN 296-8251-5-ND
U3: Z80CPU; DIP-40_W15.24mm

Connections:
+3.3V: C2.1, J1.1 (VTref), R1.1, R2.1, R3.1, R4.1, R5.1, U1.36 (3V3), U3.11 (VCC)
+5V: C1.2, C3.2, U1.40 (VBUS), U2.16 (VCC), U4.16 (VCC)
/Shift_Even: R6.2, R7.1, U1.1 (GPIO0)
/Shift_Odd: R16.2, R17.1, U1.2 (GPIO1)
/Z80_A0: U2.11 (A), U3.30 (A0)
/Z80_A1: U3.31 (A1), U4.11 (A)
/Z80_A2: U2.12 (B), U3.32 (A2)
/Z80_A3: U3.33 (A3), U4.12 (B)
/Z80_A4: U2.13 (C), U3.34 (A4)
/Z80_A5: U3.35 (A5), U4.13 (C)
/Z80_A6: U2.14 (D), U3.36 (A6)
/Z80_A7: U3.37 (A7), U4.14 (D)
/Z80_A8: U2.3 (E), U3.38 (A8)
/Z80_A9: U3.39 (A9), U4.3 (E)
/Z80_A10: U2.4 (F), U3.40 (A10)
/Z80_A11: U3.1 (A11), U4.4 (F)
/Z80_A12: U2.5 (G), U3.2 (A12)
/Z80_A13: U3.3 (A13), U4.5 (G)
/Z80_A14: U2.6 (H), U3.4 (A14)
/Z80_A15: U3.5 (A15), U4.6 (H)
/Z80_D0: R8.2, U1.12 (GPIO9)
/Z80_D1: R9.2, U1.14 (GPIO10)
/Z80_D2: R10.2, U1.15 (GPIO11)
/Z80_D3: R11.2, U1.16 (GPIO12)
/Z80_D4: R12.2, U1.17 (GPIO13)
/Z80_D5: R13.2, U1.19 (GPIO14)
/Z80_D6: R14.2, U1.20 (GPIO15)
/Z80_D7: R15.2, U1.21 (GPIO16)
/~RESET: J1.10 (~RESET), SW1.1, U1.30 (RUN)
/~Shift_Clock: U1.7 (GPIO5), U2.2 (CLK), U4.2 (CLK)
/~Shift_Latch: U1.9 (GPIO6), U2.1 (SH/~LD), U4.1 (SH/~LD)
/~Z80_CLK: U1.6 (GPIO4), U3.6 (~CLK)
/~Z80_HALT: U1.26 (GPIO20), U3.18 (~HALT)
/~Z80_INT: R3.2, U1.29 (GPIO22), U3.16 (~INT)
/~Z80_IORQ: U1.5 (GPIO3), U3.20 (~IORQ)
/~Z80_M1: U1.22 (GPIO17), U3.27 (~M1)
/~Z80_MREQ: U1.4 (GPIO2), U3.19 (~MREQ)
/~Z80_NMI: R4.2, U1.27 (GPIO21), U3.17 (~NMI)
/~Z80_RD: U1.10 (GPIO7), U3.21 (~RD)
/~Z80_RESET: R5.2, U1.31 (GPIO26_ADC0), U3.26 (~RESET)
/~Z80_RFSH: U1.25 (GPIO19), U3.28 (~RFSH)
/~Z80_WAIT: R2.2, U1.24 (GPIO18), U3.24 (~WAIT)
/~Z80_WR: U1.11 (GPIO8), U3.22 (~WR)
GND: C1.1, C2.2, C3.1, J1.3 (GND), J1.5 (GND), J1.9 (GNDDetect), R7.2, R17.2, SW1.2, U1.3 (GND), U1.8 (GND), U1.13 (GND), U1.18 (GND), U1.23 (GND), U1.28 (GND), U1.33 (AGND), U1.38 (GND), U1.42 (GND), U2.8 (GND), U2.10 (SER), U2.15 (CLK_INH), U3.29 (GND), U4.8 (GND), U4.10 (SER), U4.15 (CLK_INH)
unnamed: J1.2 (SWDIO/TMS), U1.43 (SWDIO)
unnamed: J1.4 (SWDCLK/TCK), U1.41 (SWCLK)
unnamed: R1.2, U3.25 (~BUSRQ)
unnamed: R6.1, U2.9 (QH)
unnamed: R8.1, U3.14 (D0)
unnamed: R9.1, U3.15 (D1)
unnamed: R10.1, U3.12 (D2)
unnamed: R11.1, U3.8 (D3)
unnamed: R12.1, U3.7 (D4)
unnamed: R13.1, U3.9 (D5)
unnamed: R14.1, U3.10 (D6)
unnamed: R15.1, U3.13 (D7)
unnamed: R16.1, U4.9 (QH)

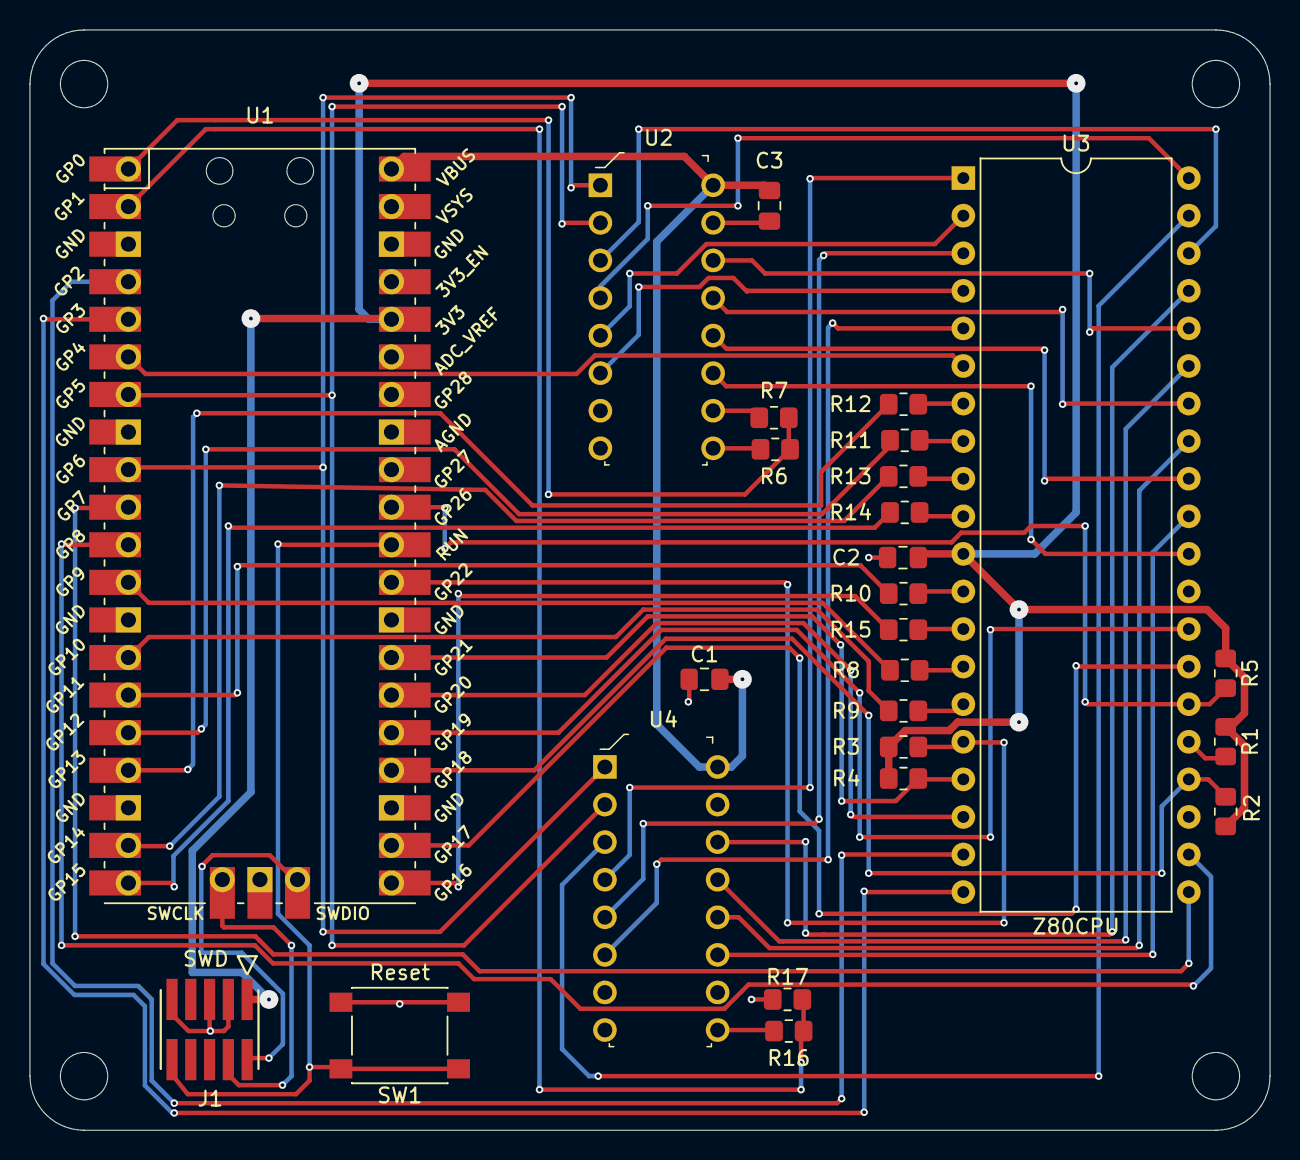
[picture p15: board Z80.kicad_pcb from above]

Board: 2 copper layers, 83.8 x 74.4 mm, 26 parts (0 on the bottom side), 57 nets.

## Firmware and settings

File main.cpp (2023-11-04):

/* Copyright 2023 Adam Green (https://github.com/adamgreen/)

   Licensed under the Apache License, Version 2.0 (the "License");
   you may not use this file except in compliance with the License.
   You may obtain a copy of the License at

       http://www.apache.org/licenses/LICENSE-2.0

   Unless required by applicable law or agreed to in writing, software
   distributed under the License is distributed on an "AS IS" BASIS,
   WITHOUT WARRANTIES OR CONDITIONS OF ANY KIND, either express or implied.
   See the License for the specific language governing permissions and
   limitations under the License.
*/
// Firmware for my Z80 Diversion.
#include <pico/stdlib.h>
#include <pico/multicore.h>
#include <signal.h>
#include <stdio.h>
#include <string.h>
#include "Z80Bus.h"
#include "mri_platform.h"

// MRI C headers
extern "C"
{
    #include <core/platforms.h>
}


// Z80 bus pin definitions.
static const uint32_t Z80_MREQ_PIN = 2;
static const uint32_t Z80_IOREQ_PIN = 3;
static const uint32_t Z80_CLK_PIN = 4;
static const uint32_t Z80_RD_PIN = 7;
static const uint32_t Z80_WR_PIN = 8;
static const uint32_t Z80_D0_PIN = 9;
static const uint32_t Z80_D1_PIN = 10;
static const uint32_t Z80_D2_PIN = 11;
static const uint32_t Z80_D3_PIN = 12;
static const uint32_t Z80_D4_PIN = 13;
static const uint32_t Z80_D5_PIN = 14;
static const uint32_t Z80_D6_PIN = 15;
static const uint32_t Z80_D7_PIN = 16;
static const uint32_t Z80_M1_PIN = 17;
static const uint32_t Z80_WAIT_PIN = 18;
static const uint32_t Z80_RFSH_PIN = 19;
static const uint32_t Z80_HALT_PIN = 20;
static const uint32_t Z80_NMI_PIN = 21;
static const uint32_t Z80_INT_PIN = 22;
static const uint32_t Z80_RESET_PIN = 26;

// Shift register pin definitions.
static const uint32_t SHIFT_EVEN_PIN = 0;
static const uint32_t SHIFT_ODD_PIN = 1;
static const uint32_t SHIFT_CLOCK_PIN = 5;
static const uint32_t SHIFT_LATCH_PIN = 6;

// The frequency at which the Z80 should be clocked.
static const uint32_t Z80_FREQUENCY = 500000;

// The number of hardware breakpoints supported by this firmware.
static const size_t   Z80_HARDWARE_BREAKPOINTS = 4;

// The number of hardware watchpoints supported by this firmware.
static const size_t   Z80_HARDWARE_WATCHPOINTS = 2;


// Pick which code to run.
static const enum
{
    RUN_DEBUGGER,
    RUN_COUNT_TEST,
    RUN_NOP_TEST
} g_runMode = RUN_DEBUGGER;

// Global for Z80 Bus object.
static Z80Bus g_z80Bus;


// Function Prototypes
static void testIncrementingZ80Code(Z80Bus& z80Bus);
static void testNOPs(Z80Bus& z80Bus);
static void runDebugger();
static void core1Z80Runner();


int main()
{
    stdio_init_all();
    while (!stdio_usb_connected())
    {
      sleep_ms(250);
    }

    // Configure the PIO state machines to manage the Z80 bus and let the RP2040 core know when memory or I/O requests
    // have been made by the Z80 so that the RP2040 core can handle them.
    bool result = g_z80Bus.init(Z80_FREQUENCY, Z80_RESET_PIN, Z80_CLK_PIN,
                                Z80_MREQ_PIN, Z80_IOREQ_PIN, Z80_RD_PIN, Z80_WR_PIN,
                                Z80_D0_PIN, Z80_D1_PIN, Z80_D2_PIN, Z80_D3_PIN,
                                Z80_D4_PIN, Z80_D5_PIN, Z80_D6_PIN, Z80_D7_PIN,
                                Z80_M1_PIN, Z80_WAIT_PIN, Z80_RFSH_PIN, Z80_HALT_PIN,
                                SHIFT_CLOCK_PIN, SHIFT_LATCH_PIN, SHIFT_EVEN_PIN, SHIFT_ODD_PIN);
    assert ( result );
    (void)result;

    switch (g_runMode)
    {
        case RUN_COUNT_TEST:
            testIncrementingZ80Code(g_z80Bus);
            break;
        case RUN_NOP_TEST:
            testNOPs(g_z80Bus);
            break;
        case RUN_DEBUGGER:
        default:
            runDebugger();
            break;
    }

    return 0;
}

static void testIncrementingZ80Code(Z80Bus& z80Bus)
{
    // Memory to be used by Z80.
    uint8_t memory[] =
    {
        // Offset 0x0:
        // LD HL, (nn)
        0x2A, 0x0A, 0x00,

        // Offset 0x3:
        // INC HL - 00 xx0 011 -  00 100 011 - 0x23
        0x23,

        // Offset 0x4:
        // LD (nn), HL
        0x22, 0x0A, 0x00,

        // Offset 0x7:
        // JP 0x0000
        0xC3, 0x00, 0x00,

        // Offset 0xA:
        // Value to increment.
        0x00, 0x00
    };
    const size_t counterOffset = sizeof(memory) - 2;

    // Trace log of what should be expected for each Z80 read/write request when running the above program.
    struct Trace
    {
        uint16_t expectedAddress;
        bool expectedM1;
        bool expectedWrite;
        bool checkCounter;
    } trace[] =
    {
        // Address, M1,     WR,     Check Counter
        { 0x0000,   true,   false,  false },
        { 0x0001,   false,  false,  false },
        { 0x0002,   false,  false,  false },
        { 0x000A,   false,  false,  false },
        { 0x000B,   false,  false,  false },
        { 0x0003,   true,   false,  false },
        { 0x0004,   true,   false,  false },
        { 0x0005,   false,  false,  false },
        { 0x0006,   false,  false,  false },
        { 0x000A,   false,  true,   false },
        { 0x000B,   false,  true,   true },
        { 0x0007,   true,   false,  false },
        { 0x0008,   false,  false,  false },
        { 0x0009,   false,  false,  false }
    };

    volatile uint16_t expectedCount = 0x0000;
    volatile size_t traceIndex = 0;
    while (true)
    {
        // Fetch next read/write transfer request.
        volatile struct Z80Bus::Request req;
        z80Bus.getNextRequest((Z80Bus::Request*)&req);
        assert ( req.address < sizeof(memory) );
        assert ( req.isMReq );

        // Verify that this request matches the expected trace.
        volatile Trace* pTrace = &trace[traceIndex];
        assert ( pTrace->expectedAddress == req.address );
        assert ( pTrace->expectedM1 == req.isM1 );
        assert ( pTrace->expectedWrite == !req.isRead );

        // Perform the memory read or write from/to RAM and send response to Z80 via PIO.
        bool isRead = req.isRead;
        uint16_t address = req.address;
        if (isRead)
        {
            req.value = memory[address];
            if (Z80_FREQUENCY <= 1000)
            {
                printf("[%04X]->%02X %s\r\n", req.address, req.value, req.isM1 ? "M1" : "");
            }
        }
        else
        {
            memory[address] = req.value;
            if (Z80_FREQUENCY <= 1000)
            {
                printf("[%04X]<-%02X\r\n", req.address, req.value);
            }
        }
        z80Bus.completeRequest((Z80Bus::Request*)&req);

        // Check the 16-bit counter right after it has been written.
        if (pTrace->checkCounter)
        {
            uint16_t counter;
            expectedCount++;
            memcpy(&counter, &memory[counterOffset], sizeof(counter));
            assert ( counter == expectedCount );
        }
        traceIndex = (traceIndex + 1) % (sizeof(trace)/sizeof(trace[0]));
    }
}

static void testNOPs(Z80Bus& z80Bus)
{
    volatile uint16_t expectedAddress = 0x0000;
    while (true)
    {
        // Fetch next read/write transfer request.
        Z80Bus::Request req;
        z80Bus.getNextRequest(&req);

        // Every request should be a read from an ascending address.
        assert ( req.isMReq );
        assert ( req.isRead );
        assert ( req.address == expectedAddress++ );
        (void)expectedAddress;

        uint8_t NOP = 0x00;
        req.value = NOP;
        z80Bus.completeRequest(&req);

        // Display some output every once in awhile to let the user know it is still running.
        if ((req.address & 0x00FF) == 0x0000)
        {
            printf("%04X\r\n", req.address);
        }
    }
}




// Commands that can be sent to the Z80 control thread.
enum Z80Commands
{
    // Just hold Z80 in WAIT state.
    COMMAND_PAUSE,
    // Let the Z80 run normally.
    COMMAND_RUN,
    // Use "RST 8" to halt Z80 and grab context.
    COMMAND_HALT,
    // Resume after Z80 has been halted. Only sent when control thread is in STATE_HALTED state.
    COMMAND_HALT_RESUME,
    // Resume after Z80 has been halted and reset. Skip register popping. Only sent when control thread is in
    // STATE_HALTED state.
    COMMAND_HALT_RESET_RESUME,
    // Let one M1 through and then enter halt mode like COMMAND_HALT.
    COMMAND_SINGLE_STEP
};

// States that the Z80 control thread can be in.
enum Z80States
{
    // Most recent Z80 memory request is left in WAIT state. Stay in this state as long as g_command is COMMAND_PAUSE.
    STATE_PAUSED,
    // Z80 is allowed to run normally from the RAM contents in g_memory.
    STATE_RUNNING,
    // Start single stepping mode. Insert a "RST 8" after one M1' cycle has been received.
    STATE_SINGLE_STEP_START,
    // Wait for next instruction fetch and return "RST 8" in its place.
    STATE_HALT_START,
    // Waiting for 1st RST 8 vector instruction to be fetched. Also records the 2 most recent memory writes as they will
    // be the automatic push of the PC to the stack pointed to by SP. This is where the value of SP is discovered.
    STATE_HALT_WAIT_RST8_VECTOR,
    // Z80 is now given code which pushes all of the registers to the stack.
    STATE_HALT_PUSHING,
    // All registers have been pushed to the stack and then copied over to g_registers.
    // Waits for COMMAND_HALT_RESUME in g_command before continuing to next state.
    STATE_HALTED,
    // The contents of g_registers (may have been modified by GDB) are copied back onto the stack.
    // The Z80 is then given code which pops all of the registers from the stack.
    STATE_HALT_POPPING,
    // The Z80 has returned to start executing at PC but is held in WAIT state until g_command is set to something other
    // than COMMAND_HALT_RESUME.
    STATE_HALT_DONE
};

// Globals used for communication between Core0 and Core1 for Z80 control.
static volatile Z80Commands g_command = COMMAND_PAUSE;
static volatile Z80States   g_state = STATE_PAUSED;

// 64k of RAM used for satisfying Z80 memory requests.
static uint8_t g_memory[DEBUGGER_MEMORY_SIZE];

// Z80 register contents when it is halted.
static Z80Registers g_registers;

// Array of hardware breakpoints.
static uint32_t g_breakpoints[Z80_HARDWARE_BREAKPOINTS];

// Array of hardware watchpoints.
static Z80Watchpoint g_watchpoints[Z80_HARDWARE_WATCHPOINTS];

// Reason for debug trap.
PlatformTrapReason g_reason;


static void handlePauseState(Z80Bus::Request* pReq);
static void handleRunningState(Z80Bus::Request* pReq);
static bool doesMatchWatchpoint(uint32_t address, PlatformWatchpointType type);
static void handleSingleStepStartState(Z80Bus::Request* pReq);
static void handleHaltStartState(Z80Bus::Request* pReq);
static void handleHaltWaitRst8State(Z80Bus::Request* pReq);
static void handleHaltPushingState(Z80Bus::Request* pReq);
static uint16_t readHalfWord(uint16_t address);
static void handleHaltedState(Z80Bus::Request* pReq);
static void writeHalfWord(uint16_t address, uint16_t value);
static void handleHaltPoppingState(Z80Bus::Request* pReq);
static void handleHaltDoneState(Z80Bus::Request* pReq);

// UNDONE: Temporary.
static const uint8_t g_testProgram[] =
{
    // LD SP, 0x0000
    0x31, 0x00, 0x00,
    // LD A, 0x14
    0x3E, 0x14,
    // LD I, A
    0xED, 0x47,
    // LD A, 0x15
    0x3E, 0x15,
    // LD R, A
    0xED, 0x4F,
    // LD BC, 0x0001
    0x01, 0x01, 0x00,
    // PUSH BC
    0xC5,
    // POP AF
    0xF1,
    // LD BC, 0x0203
    0x01, 0x03, 0x02,
    // LD DE, 0x0405
    0x11, 0x05, 0x04,
    // LD HL, 0x0607
    0x21, 0x07, 0x06,
    // LD IX, 0x0809
    0xDD, 0x21, 0x09, 0x08,
    // LD IY, 0x0A0B
    0xFD, 0x21, 0x0B, 0x0A,
    // EXX
    0xD9,
    // EX AF, AF'
    0x08,
    // LD BC, 0x0C0D
    0x01, 0x0D, 0x0C,
    // PUSH BC
    0xC5,
    // POP AF
    0xF1,
    // LD BC, 0x0E0F
    0x01, 0x0F, 0x0E,
    // LD DE, 0x1011
    0x11, 0x11, 0x10,
    // LD HL, 0x1213
    0x21, 0x13, 0x12,
    // EX AF, AF'
    0x08,
    // EXX
    0xD9,
    // JR 0
    0x18, (uint8_t)-2
};

static void runDebugger()
{
    // Fill the Z80 RAM with NOPs (0x00).
    memset(g_memory, 0, sizeof(g_memory));

    // UNDONE: Temp test code.
    memcpy(g_memory, g_testProgram, sizeof(g_testProgram));

    // Initialize the MRI core.
    initDebugger(g_memory, sizeof(g_memory),
                 g_breakpoints, sizeof(g_breakpoints)/sizeof(g_breakpoints[0]),
                 g_watchpoints, sizeof(g_watchpoints)/sizeof(g_watchpoints[0]));

    // Initialize the globals used to communicate between the 2 cores.
    g_command = COMMAND_PAUSE;
    g_state = STATE_PAUSED;

    // Run the Z80 memory request handling code on its own core (Core1).
    multicore_reset_core1();
    multicore_launch_core1(core1Z80Runner);

    // Now infinite loop between the Z80 running on its own or halted in GDB.
    bool wasInterrupted = false;
    while (true)
    {
        if ((g_state == STATE_PAUSED || g_state == STATE_RUNNING) && Platform_CommHasReceiveData())
        {
            // GDB is sending commands so halt the Z80.
            g_command = COMMAND_HALT;
            wasInterrupted = true;
        }

        if (g_state == STATE_HALTED)
        {
            // The Z80 is halted so enter MRI to allow GDB to debug it.
            enterDebugger(&g_registers, wasInterrupted ? SIGINT : SIGTRAP, &g_reason);
            wasInterrupted = false;
            g_reason.type = MRI_PLATFORM_TRAP_TYPE_UNKNOWN;

            if (shouldReset())
            {
                // Reset the Z80 and prepare to resume the CPU without restoring register contents.
                g_z80Bus.resetZ80();
                g_command = COMMAND_HALT_RESET_RESUME;
            }
            else
            {
                // Debugging is complete so restore the Z80 registers and prepare to resume the CPU.
                g_command = COMMAND_HALT_RESUME;
            }

            while (g_state != STATE_HALT_DONE)
            {
                // Wait for the Z80 control thread to finish processing the resume command.
            }

            if (Platform_IsSingleStepping())
            {
                g_command = COMMAND_SINGLE_STEP;
            }
            else
            {
                g_command = COMMAND_RUN;
            }
        }
    }
}

static void __not_in_flash_func(core1Z80Runner)()
{
    // This is the Z80 control thread which runs out of RAM on the second core, Core1.
    // The second core is used so that things like the USB stack don't steal away CPU cycles from servicing Z80 memory
    // requests.
    // It runs out of RAM so that FLASH wait cycles don't slow down the servicing of Z80 memory requests.
    Z80Bus::Request req;
    // Just keep looping around forever in this thread, pulling Z80 memory requests from the PIO FIFO.
    // They will be serviced by a state machine which knows how to handle single stepping, halting, breakpoints, etc.
    while (true)
    {
        // The state machine automatically transitions from one state to the next state except when it is PAUSED,
        // RUNNING, or HALT_DONE.
        bool switchableState;
        switch (g_state)
        {
            case STATE_PAUSED:
            case STATE_RUNNING:
            case STATE_HALT_DONE:
                switchableState = true;
                break;
            default:
                switchableState = false;
                break;
        }

        // See if the main thread has sent a new command that should cause a switch into a new state.
        if (switchableState)
        {
            switch (g_command)
            {
                case COMMAND_PAUSE:
                    g_state = STATE_PAUSED;
                    break;
                case COMMAND_RUN:
                    g_state = STATE_RUNNING;
                    break;
                case COMMAND_SINGLE_STEP:
                    g_state = STATE_SINGLE_STEP_START;
                    break;
                case COMMAND_HALT:
                    g_state = STATE_HALT_START;
                    break;
                default:
                    break;
            }
        }

        if (req.isCompleted)
        {
            // Fetch next read/write transfer request.
            g_z80Bus.getNextRequest(&req);
            assert ( req.isMReq );
        }

        // What to run next depends on the current state of the control thread.
        switch (g_state)
        {
            case STATE_PAUSED:
                handlePauseState(&req);
                break;
            case STATE_RUNNING:
                handleRunningState(&req);
                break;
            case STATE_SINGLE_STEP_START:
                handleSingleStepStartState(&req);
                break;
            case STATE_HALT_START:
                handleHaltStartState(&req);
                break;
            case STATE_HALT_WAIT_RST8_VECTOR:
                handleHaltWaitRst8State(&req);
                break;
            case STATE_HALT_PUSHING:
                handleHaltPushingState(&req);
                break;
            case STATE_HALTED:
                handleHaltedState(&req);
                break;
            case STATE_HALT_POPPING:
                handleHaltPoppingState(&req);
                break;
            case STATE_HALT_DONE:
                handleHaltDoneState(&req);
                break;
            default:
                assert ( false );
                break;
        }
   }
}

// Most recent Z80 memory request is left in WAIT state. Stay in this state as long as g_command is COMMAND_PAUSE.
static void __not_in_flash_func(handlePauseState)(Z80Bus::Request* pReq)
{
    while (g_command == COMMAND_PAUSE)
    {
        // Wait here with Z80 WAIT' signal asserted until pause is undone.
    }

    // Current request is left outstanding.
    // It was just left in a WAIT' state all this time.
}

// Z80 is allowed to run normally, reading and writing from/to the RAM contents in g_memory.
static void __not_in_flash_func(handleRunningState)(Z80Bus::Request* pReq)
{
    // Perform the memory read or write from/to RAM and send response to Z80 via PIO.
    bool isRead = pReq->isRead;
    bool isM1 = pReq->isM1;
    bool isMReq = pReq->isMReq;
    bool wasPrefixDetected = pReq->wasPrefixDetected;
    uint16_t address = pReq->address;
    if (isRead)
    {
        if (doesMatchWatchpoint(address, MRI_PLATFORM_READ_WATCHPOINT))
        {
            // There is a watchpoint on this read so leave this request outstanding.
            // Will be processed by next state.
            g_state = STATE_HALT_START;
            return;
        }

        if (isMReq && isM1 && !wasPrefixDetected)
        {
            for (size_t i = 0 ; i < sizeof(g_breakpoints)/sizeof(g_breakpoints[0]) ; i++)
            {
                if (g_breakpoints[i] == address)
                {
                    // There is a breakpoint on this instruction so leave this request outstanding.
                    // Will be processed by next state.
                    g_state = STATE_HALT_START;
                    g_reason.type = MRI_PLATFORM_TRAP_TYPE_HWBREAK;
                    g_reason.address = address;
                    return;
                }
            }
        }

        // Process memory reads from RAM.
        pReq->value = g_memory[address];
    }
    else
    {
        if (doesMatchWatchpoint(address, MRI_PLATFORM_WRITE_WATCHPOINT))
        {
            // There is a watchpoint on this write so leave this request outstanding.
            // Will be processed by next state.
            g_state = STATE_HALT_START;
            return;
        }

        g_memory[address] = pReq->value;
    }
    g_z80Bus.completeRequest(pReq);
}

static bool __not_in_flash_func(doesMatchWatchpoint)(uint32_t address, PlatformWatchpointType type)
{
    for (size_t i = 0 ; i < sizeof(g_watchpoints)/sizeof(g_watchpoints[0]) ; i++)
    {
        if (address >= g_watchpoints[i].startAddress &&
            address < g_watchpoints[i].endAddress &&
            (g_watchpoints[i].type & type) != 0)
        {
            switch (g_watchpoints[i].type)
            {
                case MRI_PLATFORM_WRITE_WATCHPOINT:
                    g_reason.type = MRI_PLATFORM_TRAP_TYPE_WATCH;
                    break;
                case MRI_PLATFORM_READ_WATCHPOINT:
                    g_reason.type = MRI_PLATFORM_TRAP_TYPE_RWATCH;
                    break;
                case MRI_PLATFORM_READWRITE_WATCHPOINT:
                    g_reason.type = MRI_PLATFORM_TRAP_TYPE_AWATCH;
                    break;
            }
            g_reason.address = g_watchpoints[i].startAddress;

            return true;
        }
    }

    return false;
}



// RST 8 vector handler starts at this address.
static const uint16_t RST8_VECTOR_ADDRESS = 0x0008;

// Register pushing code to save all Z80 registers to the stack.
static const uint8_t g_rst8PushCode[] =
{
    // PUSH AF
    0xF5,
    // PUSH BC
    0xC5,
    // PUSH DE
    0xD5,
    // PUSH HL
    0xE5,
    // PUSH IX
    0xDD, 0xE5,
    // PUSH IY
    0xFD, 0xE5,
    // EXX
    0xD9,
    // EXX AF, AF'
    0x08,
    // PUSH AF
    0xF5,
    // PUSH BC
    0xC5,
    // PUSH DE
    0xD5,
    // PUSH HL
    0xE5,
    // LD A, R
    0xED, 0x5F,
    // LD C, A
    0x4F,
    // LD A, I
    0xED, 0x57,
    // LD B, A
    0x47,
    // PUSH BC
    0xC5

};
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

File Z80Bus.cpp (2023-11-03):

/* Copyright 2023 Adam Green (https://github.com/adamgreen/)

   Licensed under the Apache License, Version 2.0 (the "License");
   you may not use this file except in compliance with the License.
   You may obtain a copy of the License at

       http://www.apache.org/licenses/LICENSE-2.0

   Unless required by applicable law or agreed to in writing, software
   distributed under the License is distributed on an "AS IS" BASIS,
   WITHOUT WARRANTIES OR CONDITIONS OF ANY KIND, either express or implied.
   See the License for the specific language governing permissions and
   limitations under the License.
*/
// Class which accesses the Z80 bus, leveraging the RP2040's PIO peripheral.
#include <hardware/clocks.h>
#include <hardware/pwm.h>
#include <pico/stdlib.h>
#include <Z80Bus.pio.h>
#include "Z80Bus.h"

bool Z80Bus::init(uint32_t frequency,
                   uint32_t resetPin, uint32_t z80ClockPin,
                   uint32_t mreqPin, uint32_t ioreqPin,
                   uint32_t rdPin, uint32_t wrPin,
                   uint32_t d0Pin, uint32_t d1Pin, uint32_t d2Pin, uint32_t d3Pin,
                   uint32_t d4Pin, uint32_t d5Pin, uint32_t d6Pin, uint32_t d7Pin,
                   uint32_t m1Pin, uint32_t waitPin, uint32_t rfshPin, uint32_t haltPin,
                   uint32_t shiftClockPin, uint32_t shiftLatchPin, uint32_t shiftEvenPin, uint32_t shiftOddPin)
{
    // Verify that the side set pins are in ascending pin number order.
    assert ( shiftLatchPin == shiftClockPin + 1 );
    // Verify that the input pins are in ascending pin number order.
    assert ( shiftOddPin == shiftEvenPin + 1);
    assert ( mreqPin = shiftOddPin + 1 );
    assert ( ioreqPin == mreqPin + 1 );
    assert ( wrPin == rdPin + 1 );
    assert ( d0Pin == wrPin + 1 );
    assert ( d1Pin == d0Pin + 1 );
    assert ( d2Pin == d1Pin + 1 );
    assert ( d3Pin == d2Pin + 1 );
    assert ( d4Pin == d3Pin + 1 );
    assert ( d5Pin == d4Pin + 1 );
    assert ( d6Pin == d5Pin + 1 );
    assert ( d7Pin == d6Pin + 1 );
    assert ( m1Pin == d7Pin + 1);

    // Cleanup the PIO if it was already initialized before continuing to initialize it again, with probably different
    // parameters (ie. frequency).
    uninit();

    manualResetZ80(resetPin, z80ClockPin, frequency);

    if (!initAddressStateMachine(frequency, waitPin, shiftClockPin, shiftLatchPin, shiftEvenPin, shiftOddPin, mreqPin, ioreqPin, rfshPin) ||
        !initReadWriteStateMachine(rdPin, wrPin, d0Pin, d1Pin, d2Pin, d3Pin, d4Pin, d5Pin, d6Pin, d7Pin, m1Pin))
    {
        uninit();
        return false;
    }
    initClock(frequency, z80ClockPin);
    cacheWaitInstructionOpCodes();

    m_haltPin = haltPin;

    return true;
}

void Z80Bus::manualResetZ80(uint32_t z80ResetPin, uint32_t z80ClockPin, uint32_t z80Frequency)
{
    // Configure pins connected to the Z80 CLK and RESET' signals as output.
    const uint32_t clockPinMask = 1 << z80ClockPin;
    const uint32_t resetPinMask = 1 << z80ResetPin;
    const uint32_t pinMask = clockPinMask | resetPinMask;
    // Start out with both the Z80 CLK and RESET' signals low.
    gpio_clr_mask(pinMask);
    // Configure these pins as SIO outputs.
    gpio_set_dir_out_masked(pinMask);
    gpio_set_function(z80ResetPin, GPIO_FUNC_SIO);
    gpio_set_function(z80ClockPin, GPIO_FUNC_SIO);

    // Reset the Z80 by manually clocking it for 4 cycles while asserting the RESET' pin low.
    uint32_t sleepTime = 1000000 / (z80Frequency * 2);
    if (sleepTime == 0)
    {
        sleepTime = 1;
    }
    for (int i = 0 ; i < 4 ; i++)
    {
        sleep_us(sleepTime);
        gpio_set_mask(clockPinMask);
        sleep_us(sleepTime);
        gpio_clr_mask(clockPinMask);
    }

    // De-assert the RESET' pin.
    gpio_set_mask(resetPinMask);

    // Remember the reset pin.
    m_resetPin = z80ResetPin;
}

bool Z80Bus::initAddressStateMachine(uint32_t frequency, uint32_t waitPin,
                                      uint32_t shiftClockPin, uint32_t shiftLatchPin,
                                      uint32_t shiftEvenPin, uint32_t shiftOddPin, uint32_t mreqPin, uint32_t ioreqPin,
                                      uint32_t rfshPin)
{
    if (initAddressStateMachine(pio0, frequency, waitPin, shiftClockPin, shiftLatchPin, shiftEvenPin, shiftOddPin, mreqPin, ioreqPin, rfshPin) ||
        initAddressStateMachine(pio1, frequency, waitPin, shiftClockPin, shiftLatchPin, shiftEvenPin, shiftOddPin, mreqPin, ioreqPin, rfshPin))
    {
        return true;
    }
    return false;
}



bool Z80Bus::initAddressStateMachine(PIO pio, uint32_t frequency, uint32_t waitPin,
                                      uint32_t shiftClockPin, uint32_t shiftLatchPin,
                                      uint32_t shiftEvenPin, uint32_t shiftOddPin, uint32_t mreqPin, uint32_t ioreqPin,
                                      uint32_t rfshPin)
{
    // See if the PIO code for the address state machine will fit in this PIO instance with a free state machine.
    if (!pio_can_add_program(pio, &z80AddressStateMachine_program))
    {
        return false;
    }
    int32_t stateMachine = pio_claim_unused_sm(pio, false);
    if (stateMachine == -1)
    {
        return false;
    }

    // Remember the pins along with PIO instance and state machine.
    m_waitPin = waitPin;
    m_shiftClockPin = shiftClockPin;
    m_shiftLatchPin = shiftLatchPin;
    m_shiftEvenPin = shiftEvenPin;
    m_shiftOddPin = shiftOddPin;
    m_mreqPin = mreqPin;
    m_ioreqPin = ioreqPin;
    m_rfshPin = rfshPin;
    m_addressPIO = pio;
    m_addressStateMachine = stateMachine;

    // Load the PIO program.
    m_addressProgramOffset = pio_add_program(pio, &z80AddressStateMachine_program);

    // Update the "wait 1 gpio rfshPin side 0b10" instruction at the beginning of this state machine's instruction
    // stream as rfshPin is not provided to the PIO assembler.
    m_addressPIO->instr_mem[m_addressProgramOffset + z80AddressStateMachine_offset_wait_instr] =
        pio_encode_wait_gpio(true, m_rfshPin) | pio_encode_sideset(2, 0b10);
    m_waitMREQInstruction = pio_encode_wait_gpio(true, m_mreqPin) | pio_encode_sideset(2, 0b10);

    // Fetch the default state machine configuration for running this PIO program on a state machine.
    pio_sm_config smConfig = z80AddressStateMachine_program_get_default_config(m_addressProgramOffset);

    // Side Set needs to be configured for the Shift Clock and Latch pins.
    sm_config_set_sideset_pins(&smConfig, m_shiftClockPin);

    // SET pins should be configured for the WAIT' pin.
    sm_config_set_set_pins(&smConfig, m_waitPin, 1);
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

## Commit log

2023-09-02 Update README
    The parts have arrived from Digikey. I have added photos of the 3 main
    BOM items now that I have them in my possession.
2023-09-02 Added initial schematic
    This should be enough to get me started on the breadboarding portion of
    this project.
    [Z80.kicad_pcb, Z80.kicad_sch]
2023-09-15 Initial firmware commit
    This is a simple little program that makes sure that the RP2040 and its
    PIO hardware can be used to clock the Z80 microprocessor and satisfy
    its memory requests. It runs a simple Z80 program that increments a
    16-bit counter in a loop and verifies that this counter is incremented
    as expected.
    * Updated README to cover the latest developments on this project.
    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
    [Z80.kicad_sch]
2023-09-15 Update schematic
    [Z80.kicad_sch]
2023-09-16 Initial PCB design
    * Designed version 1.1 of the PCB and sent it off to OSHPark to have it
    fabricated.
    * Fixed a missing connection between 3.3V and a bunch of Z80 pull-ups
    that I had in my schematic that I didn't notice until I was working
    on the PCB.
    * Updated README with the latest project progression.
    [Z80.kicad_pcb, Z80.kicad_sch]
2023-09-19 Update README
    * Got Z80 fork of binutils and GDB building on my Mac.
    * OSHPark has started making my boards.
2023-10-07 Update README
    Added notes after receiving and soldering up version 1.1 of the PCBs.
    [Z80-bom.csv]
2023-10-11 Rewrite of PIO code
    I rewrote both the PIO state machines to be more async in nature. Now
    they both just look for edges in signals such as MREQ', IOREQ', RD',
    and WR' while ignoring the Z80 clock signal itself. This greatly
    simplified the first state machine's code since it no longer has to
    generate the Z80 clock while also checking for memory requests and
    shifting out the address bits.
    I am currently generating the Z80 clock signal from a third state
    machine but in the future I will probably generate it using the PWM
    peripheral instead.
    I still have a few bug fixes and performance improvements to make to
    these PIO programs but I feel like I am getting close now.
    [main.cpp]
2023-10-11 Add more tests
    Still running the same simple 16-bit counter incrementing program on
    the Z80 but now the C++ code on the RP2040 verifies that every Z80
    memory access is as expected:
    * Read or Write access.
    * Address of access.
    * M1' state of access.
    It also checks the value of the 16-bit counter right after the write to
    it from the Z80 has completed.
    These new tests let me see exactly what causes things to go awry when I
    attempt to run the Z80 at higher clock rates. I can now run it
    successfully at 700kHz but it fails at 800kHz. These tests helped me
    track down the point of failure and see that the fall time of the shift
    register was too slow for the 12.5 MHz shift register clocking rate
    us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
    [main.cpp]
2023-10-11 Run AddressStateMachine 4x faster
    I added 4x delay to the shift register clocking instructions themselves
    and then run the state machine 4x faster to reduce the time between
    MREQ'/IOREQ' being assserted and the start of the address shifting.
    When running at 700kHz, this shaves off 130µs.
    I tried 8x but this generates too fast of a state machine frequency so
    I used 4x instead. This will break at Z80 frequencies above 976kHz but
    currently I have hardware issues that prevent me from getting to such
    speeds anyway.
    [main.cpp]
2023-10-12 Remove redundant shift register clock pulse
    The way the PIO code was written before, a full 8 clock cycles were
    sent to the pair of shift registers but only 7 are required since the
    first bit is ready at the time of latching. It did require adding 2
    more PIO instructions to generate these fewer clock pulses though.
    When running the Z80 at 750kHz this gives an additional 112ns between
    the time the shifts complete and the next Z80 clock falling edge, the
    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
2023-10-12 Use asymmetric shift register clock
    The shift register has a maximum clock frequency of 50MHz when run at
    5.0V so it can go faster than the 12.5MHz limit that I hit because of
    the slow rise/fall times on its outputs. It is only the high portion of
    the clock that accounts for this rise/fall time before it is sampled by
    the PIO on the falling edge. The low portion of the clock can be much
    shorter and not cause any problem. That means if I run the clock
    asymmetrically then I can get the benefits of the higher shift rate and
    still have time for the outputs to rise/fall. I now run the
    AddressStateMachine at a fixed 125MHz which results in a shift register
    clock rate of 15.625MHz. The shift clock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
    [main.cpp]
2023-10-12 Handle changing RFSH' pin assignment
    Previously the RFSH' pin assignment to GPIO 19 was hardcoded in
    the z80_bus.pio assembly language file. rfshPin is provided as a
    parameter to Z80_Bus::initAddressStateMachine() and this commit
    modifies it to overwrite the machine code for this instruction with
    the correct "wait 1 gpio rfshPin side 0b10". This makes it easier to
    change in the future like the rest of the pins.
    [main.cpp]
2023-10-12 Some code cleanup
    * Remove ClockStateMachine and just use PWM for clocking the Z80
    instead. This saves 2 PIO instructions.
    * Renamed the PIO assembly language routines for the 2 remaining
    state machines to match the names I use elsewhere in the code.
    * Refactored the Z80_Bus::Request structure to use 16-bits for the
    address and 8-bits for the value members.
2023-10-23 Added debugger support
    GDB can now attach over the USB Serial port to debug the Z80. It
    supports:
    * Memory read/writes
    * Register reads/writes
    * CTRL+C halting
    * Single stepping
    * 4 Hardware Breakpoints
    * 2 Hardware Watchpoints
    I pulled MRI in as a submodule. I had to update it so that it would
    support 16-bit registers and addresses like used by the Z80 port of
    GDB.
    I pulled the Z80 bus handling code out into its own module.
    I now run the Z80 memory request handling CPU code on the second RP2040
    core so that it doesn't get glitches when the CPU is interrupted by
    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
    [Z80Bus.cpp, Z80Bus.h, main.cpp]
2023-10-23 Update README
    Just cleaned it up a bit and added notes now that the first version of
    the PCB and firmware are up and running as needed.
2023-10-31 Upgrade PCB design to KiCAD 7
2023-10-31 GDB can now handle SP being set to 0x0000
    - Added the diff for my GDB SP fix to the README.
    - Updated test program in main.cpp to initialize SP to 0x0000 as I had
    originally written it now that it doesn't cause problems for GDB.
    - Added explicit carriage return to printf() statements now that I have
    turned off end of line translation so that it doesn't corrupt packets
    sent to GDB.
    [main.cpp]
2023-11-01 Add sample GDB session to README
    This will help me to remember what I can and can't do with this debugger
    setup in the future.
2023-11-03 Add "monitor reset" support
    Can now use the "monitor reset" command in GDB to perform a hardware
    reset on the Z80.
    * The Z80Bus class already had code which would reset the Z80 as part of
    of its existing init() method. To perform a later reset all I had to
    do was call uninit() and then init() again. This resets the PIO state
    machines and the Z80 device as expected.
    * The Z80 control thread's state machine had to be modified to support
    a new COMMAND_HALT_RESET_RESUME command to discard the last Z80
    memory request and skip the register popping state since the Z80 has
    already been reset by the time this command is sent from the main
    thread.
    * Updated README to document this new s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
    [Z80Bus.cpp, Z80Bus.h, main.cpp]
